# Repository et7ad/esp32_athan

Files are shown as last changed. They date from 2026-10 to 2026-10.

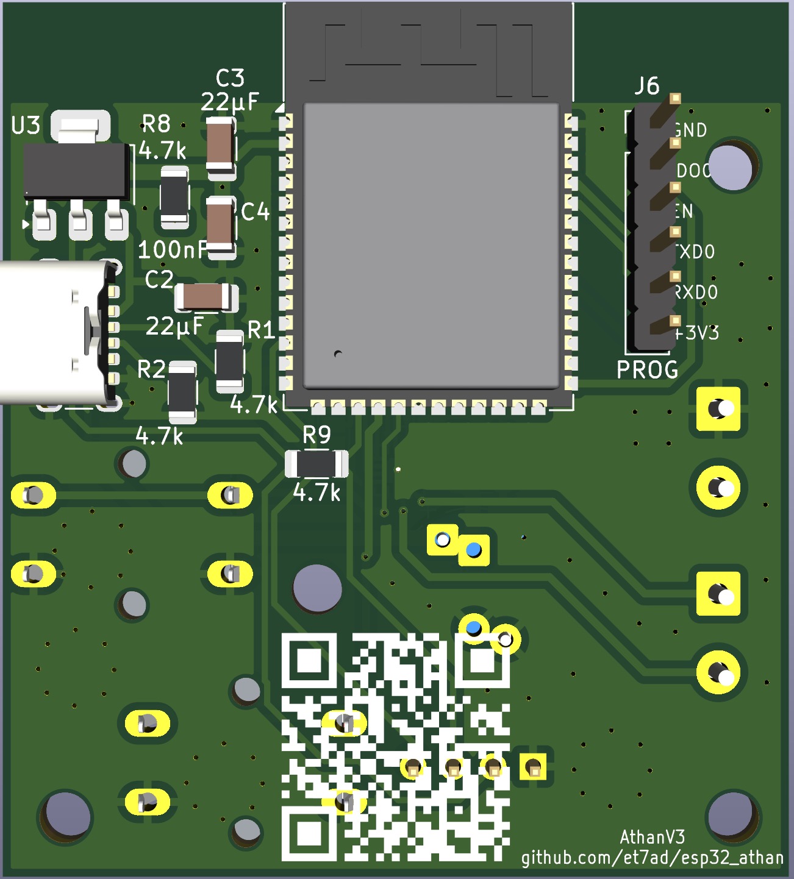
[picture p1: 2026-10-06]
hardware/pcb/generated_imgs_and_3d/Front_with_3D.jpg

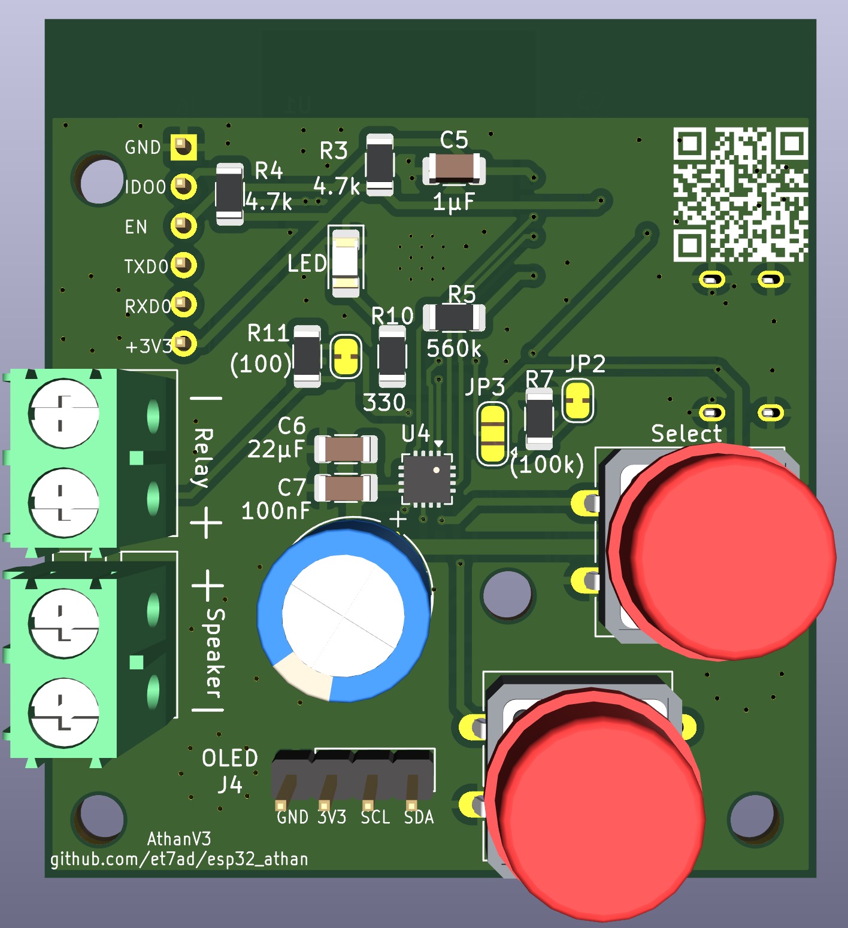
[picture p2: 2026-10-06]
hardware/pcb/generated_imgs_and_3d/Back_with_3D.jpg

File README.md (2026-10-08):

# Athan clock, version 3 (ESP32-S3)

A small Wi-Fi clock that calls the athan at the prayer times of your mosque, shows the time and the next prayer on
a little OLED screen, plays Quran radio, and can switch an external relay (for example a mosque speaker) before
Fajr. Version 3 runs on an ESP32-S3 with a MAX98357A amplifier: the audio is stored in the ESP's own flash and
played by the ESP itself.

> **Have an older clock (ESP8266 + DFPlayer, "V2")?** Its firmware and prayer data live in
> [et7ad/esp_athan](https://github.com/et7ad/esp_athan). That repository is kept only to support existing V2
> devices. New builds should use this repository.

**Status (October 2026):** firmware 3.0.0 is written and type-checked but **not yet tested on hardware**. The
prototype checklist is in [version3_planning.md](version3_planning.md) section 13. The board (KiCad) and the
enclosure are still to be drawn from [HARDWARE.md](HARDWARE.md).

## What it does

- Calls the athan at Dhuhr, Asr, Maghrib and Isha, and a separate Fajr athan at Fajr, each at its own volume.
  Each prayer can be switched off on its own.
- Keeps a whole year of your mosque's prayer times in flash. Once the clock is set, the athan keeps working
  without internet.
- Plays internet radio from ten slots. By default they follow this project's station list; any slot can play
  your own link instead.
- **Pre-Fajr Tawashih:** 25 minutes before Fajr it switches the relay on, plays a tawashih, and switches the
  relay off after 15 minutes. Off by default.
- Plays an hourly tick inside a time window you choose, or not at all.
- Every sound (athan, Fajr athan, tawashih, tick) can be swapped for another from the project's list, or for a
  file you upload. Each file is checked before it replaces the old one.
- It is set up from a phone over Bluetooth, or through its own Wi-Fi hotspot.
- It has a web page, works with Home Assistant, and updates its own firmware from GitHub Releases.
- It keeps working without the screen: if the OLED fails, the athan still plays.

## Contents

1. [Using the clock](#1-using-the-clock)
2. [Building one](#2-building-one)
3. [Maintaining the data (project owner)](#3-maintaining-the-data-project-owner)
4. [Repository layout](#4-repository-layout)

---

## 1. Using the clock

### 1.1 First setup: connect it to Wi-Fi

Plug the clock into a USB-C charger (5 V, 2 A). A new clock, or one that cannot reach its saved network, opens
**two setup methods at once**. Use whichever suits your phone; the first one to finish wins.

**Method 1: Bluetooth (Android, computers, Home Assistant app)**

1. On an Android phone or a computer, open **Chrome** or **Edge** and go to <https://www.improv-wifi.com>. Then
   press **Connect** and pick the device named **athan**. Instead, if you use Home Assistant, the Companion app
   finds the clock by itself and offers to set it up.
2. When the screen shows **BT: press Select**, press the **Select** button on the clock. Like commercial smart-home
   devices, this proves you are standing next to it. The permission lasts one minute.
3. Choose your network and type its password. The clock joins and Bluetooth turns off.

**Method 2: hotspot (every phone, including iPhone)**

iPhones cannot use Method 1 without the Home Assistant app, because Safari has no Web Bluetooth.

1. On your phone's Wi-Fi list, join **AthanFallbackHotspot**. The password is **athan404**.
2. The setup page opens by itself. If it doesn't, open <http://192.168.4.1>.
3. Pick your network, type the password and save. The clock restarts and joins.

On a new clock both start right away. When a saved network has gone away, Bluetooth starts after 15 seconds and
the hotspot after about 3 minutes, so a short router restart never opens it.

**Forget the saved Wi-Fi:** unplug the clock, hold **Select** (press the joystick straight in), and plug it back
in. The LED blinks three times, the clock restarts, and it enters setup mode (Bluetooth after 15 seconds, the
hotspot after about 3 minutes).

**Your mosque:** a new clock starts with the first mosque in the list (Davis). Choose yours from the menu
(**Location**) or on the web page. The clock downloads that mosque's year of prayer times. It also downloads
the default sounds the first time it is online, which takes a few minutes.

### 1.2 The screen

Normal screen:

```text
14:05  05Oct        time and date
Asr 16:42 ▫         next prayer and its time
Rem 02:37      ▸ 🔒  time remaining, and status marks
```

| Mark | Meaning |
|---|---|
| Small hollow square after the next prayer's time | **Estimated time.** This year's timetable is not published yet, so the clock uses the same date of last year (converted for daylight saving; at most about a minute off). It disappears when the real timetable arrives. Mosques often publish late, sometimes days into January, so this is normal |
| Last two letters of the prayer's name struck through | The athan for that prayer is switched off |
| Small filled triangle with a number, bottom right | The radio is playing; the number is the radio slot (1–10). **Up** stops it |
| Padlock, bottom right | The buttons are locked (1.3) |
| Circled, crossed-out **W** | No Wi-Fi. The athan keeps working from the stored times |

Other screens:
- **Athan Time: Asr prayer** while the athan plays.
- **A box over the clock for 2 seconds** after Left/Right (the volume and a bar) or Down (Relay ON/OFF).
- **Struck-through rows** (lines through all three rows, with `--:--` where nothing is known) until the clock is set
  after a power-up; lines through rows 2 and 3 only until the day's prayer times are loaded. As on V2.
- **Wi-Fi setup:** while Bluetooth setup or the hotspot is open, it shows `BT: press Select` / `BT: allowed` /
  `BT: joining..` and `Hotspot: on` / `Hotspot: soon`.

### 1.3 Buttons

The clock has one **5-way joystick**: **Up**, **Down**, **Left**, **Right**, and **Select** (press it straight in).

On the clock screen:

| Key | What it does |
|---|---|
| **Left / Right** | Volume down / up by 10 %, shown for 2 seconds. It changes the volume of whatever plays (the Fajr volume during the Fajr athan or the tawashih) and never stops it. With nothing playing, a short tone plays at the new volume. The keys stop at 10 %; 0 % (silent) is only in the menu or on the web page |
| **Up** | Radio on or off. It plays the station chosen last (the number beside the play mark) |
| **Down** | Relay output on or off |
| **Select** | Opens the menu |

While the athan, the tawashih, the tick or a preview plays, **Up**, **Down** and **Select** stop it instead. The
radio is the exception: it keeps playing, so Up stops it, Select opens the menu and Down switches the relay as usual.
Stopping the athan also cancels the radio's automatic resume.

**The menu** is two wheels. **Up/Down** move between the menu's rows; the row's name is at the top, and each row is
live as soon as you reach it: no "open" step. **Left/Right** move through that row's choices. Around the item in the
middle you see small previews of what is next: the choices to the left and right, the rows above and below with
their current setting. A **check mark** marks what is in use, a **play mark** the radio station playing. Dots under
the item show where you are in the row.

**Select** takes the choice shown. Where nothing needs taking (the choice already in use, a volume, the tick
hours, Info) it closes the menu. Up from the first row or Down from the last also returns to the clock (the small
preview there says **Home**), and so does 60 seconds without a press.

| Row | Left/Right | Select |
|---|---|---|
| **Radio** | The ten radio slots (opens on the one chosen last) | Plays the slot shown, or stops it if it is playing, and returns to the clock |
| **Athan** | The suggested athans, and **Custom** first if you uploaded one. Rest on one for half a second and its preview plays; the one in use plays from the device. The row opens on the athan in use and previews it (not while the radio plays: then only Left/Right preview, and the radio comes back when the menu closes) | Downloads the one shown and makes it the athan. Progress shows under it; the old sound stays until the new one has passed every check, then the check mark moves. Custom disappears once a download replaces it |
| **Fajr Athan** | The same, for the Fajr athan. Previews play at the Fajr volume | The same |
| **Tawashih** | The same, for the Pre-Fajr Tawashih | The same |
| **Pre-Fajr** | Off, On | Takes it |
| **Hourly Tick** | The ticks, with **Off** first | Takes it; any tick switches the hourly tick on |
| **Tick From**, **Tick Until** | The hour, at once. The line under it shows the window; From = Until means all day | Closes |
| **Athan On/Off** | Fajr, Dhuhr, Asr, Maghrib, Isha, each with On/Off | Switches the prayer shown |
| **Volume**, **Fajr Volume** | 0–100 %, at once, with a tone at the new level | Closes |
| **Location** | The mosques | Takes it; the clock downloads its prayer times |
| **Clock** | 24-hour, 12-hour | Takes it |
| **Update** | — | Checks GitHub for new firmware; when there is one, the item becomes **Install 3.x.y** and Select installs it. `Check failed` means GitHub has no release yet or the clock is offline |
| **Lock Buttons** | — | Locks the buttons and returns to the clock |
| **Info** | IP address, `athan.local`, firmware version | Closes |

**Button lock**, for clocks within children's reach: while locked, any key only stops what is playing. To unlock,
use the **Buttons Locked** switch on the web page, or unplug the clock and plug it back in while holding **any of
the four directions**: the LED blinks three times quickly. (Holding Select instead forgets the Wi-Fi, 1.1.)

### 1.4 The web page

Open **<http://athan.local>**. If that doesn't work, use the IP address from the **Info** screen. The page is
grouped:

- **Now:** Stop Audio, Athan Playing, Next Prayer, Today's Times, Buttons Locked, 12-hour Clock.
- **Athan:** Volume, Fajr Volume, Pre-Fajr Tawashih, Hourly Tick, Tick Window Start / End.
- **Athan On/Off per Prayer:** one switch per prayer.
- **Sounds:** the selected sounds, the last download's status, and the link to the sounds page (1.5).
- **Radio:** Radio Station, Play Radio, Stop Radio, Radio Status.
- **Radio Stations:** the ten slots (1.6).
- **Location and Prayer Times:** Location, Refresh Prayer Times, Prayer Data (which years are stored).
- **System:** Firmware Version (this build, and whether GitHub has a newer one), Firmware (install updates), Check
  For Update, Restart, External Relay, IP address, **Wi-Fi Signal**, **Wi-Fi Drops** (when and why the router dropped
  the clock, the last three), memory.

The same entities show up in Home Assistant when you add the device there (ESPHome integration).

### 1.5 Changing the sounds: <http://athan.local/audio>

Open it from the **Change Sounds At** link on the device page, or type the address. A status bar stays at the top
of the page, with a **Stop** button for previews. Every button reports there, so the page never reloads or jumps
back to the top. After a download or upload, the bar offers **Reload page** to show the new sound. For each of
the four sounds (athan, Fajr athan, tawashih, hourly tick), the page shows:

- **Selected:** the name and length of the sound stored on the clock, the one it plays.
- **The suggested list** from this project, with **Preview** and **Download** for each entry. The selected entry is
  marked *selected*. Preview stores nothing: the selected entry plays from the clock, any other streams from the
  internet. Download fetches the entry, checks it, and only then replaces the selected sound. Downloading the
  selected entry does nothing. To fetch it again, download another entry and then this one.
- **Upload your own:** pick an MP3 file on your phone or computer and press Upload. The uploaded sound then shows
  at the top of the list as **Custom**, with **Preview**, and in the clock's menu as **Custom** too. It stays
  until you download a list entry for that sound, which replaces it.

Limits, checked before anything is replaced:

| Sound | Largest file | Longest |
|---|---|---|
| Athan, Fajr athan, tawashih | 3 MB | 5 minutes |
| Hourly tick | 0.4 MB | 1 minute |

The file must be an MP3. A 5-minute recording fits in 3 MB at 64 kbps mono.

**The clock plays only the left channel.** A mono file always plays in full. A stereo file plays only its left
channel, so the whole sound must be in that channel. A recording with something only on the right (a voice or an
echo) loses it. Converting the file to mono, as below, makes any recording safe. The amplifier is wired for left
only because its mono-mix mode caused audible artifacts during testing.

#### Quick way: an online converter (nothing to install)

1. Open [online-convert.com's MP3 converter](https://audio.online-convert.com/convert-to-mp3) (free, in the
   browser) and choose your file. It also takes WAV, M4A or a video.
2. In the optional settings, set **Change audio channels** to **Mono** and **Change audio sample rate** to
   **44100 Hz**. Set the bitrate to **64 kbps** (48 kbps for an hourly tick).
3. Convert, download the result, and upload it on the clock's `/audio` page. The clock checks every file first
   (MP3, size, length) and says what is wrong if it doesn't fit.

Your file goes to that service's servers. To keep it on your computer, or to cut a long recording to the limit,
use ffmpeg instead.

#### Preparing your own file with ffmpeg

1. Install [ffmpeg](https://ffmpeg.org) once: `brew install ffmpeg` (macOS), `winget install ffmpeg` (Windows) or
   `sudo apt install ffmpeg` (Debian, Ubuntu).
2. See what the file is:

   ```bash
   ffprobe -v error -show_entries stream=channels,sample_rate:format=duration,size -of default=nw=1 in.mp3
   ```

   `channels=1` is mono, `channels=2` is stereo. `duration` is in seconds and `size` in bytes; compare them with
   the limits above.
3. Convert it to mono. This mixes both channels into one, so nothing from either side is lost:

   ```bash
   ffmpeg -i in.mp3 -map 0:a -map_metadata -1 -ac 1 -ar 44100 -b:a 64k out.mp3
   ```

   | Part | What it does |
   |---|---|
   | `-map 0:a -map_metadata -1` | Keeps only the audio, without cover art or tags (the clock does not need them) |
   | `-ac 1` | One channel: mono |
   | `-ar 44100` | 44.1 kHz, the clock's own rate, so it plays without resampling |
   | `-b:a 64k` | 64 kbps: 5 minutes ≈ 2.4 MB. For an hourly tick use `-b:a 48k` |

   The input can be any format ffmpeg reads (WAV, M4A, a video, …). The output is MP3 because the name ends in
   `.mp3`.
4. If the mono version sounds hollow or thin (the two channels cancel each other, which is rare), or one channel
   is only noise, keep a single channel instead of mixing. Replace `-ac 1` with `-af "pan=mono|c0=c0"` for the
   left channel, or `-af "pan=mono|c0=c1"` for the right one.
5. If it is longer than the limit, add `-t 300` (5 minutes) or, for a tick, `-t 60` before `out.mp3` to cut it
   there.
6. Run the `ffprobe` command from step 2 on `out.mp3`: it should say `channels=1` and fit the limits. Then upload
   it.

A failed download, a file that is too big or
too long, or a file that is not MP3 never touches the selected sound. The page says why it refused. A download
is refused while that sound is playing.

### 1.6 Radio

There are ten slots. Each one has two settings on the web page:

- **Radio N follows project list** (on by default): the slot plays station N of this project's list,
  [docs/radio/stations.json](docs/radio/stations.json). The clock keeps the list in memory, loaded at start-up
  and refreshed every 6 hours, so a station starts at once and switching between them is quick. If a station
  moves, the project updates the list and every clock follows within 6 hours (sooner if that station stops
  working on a clock).
- **Radio N own link:** switch "follows project list" off and paste a stream link here (see "Adding your own
  station" below). The screen then shows "own link" for that slot instead of a station name.

Play it from the menu (**Radio**), or with **Radio Station** + **Play Radio** on the web page. The **Radio
Station** list shows each slot's name from the project list ("Radio 1 Cairo Quran"), "(own link)" for a slot
with its own link, and just "Radio N" until the list has loaded. Reload the page to see names that loaded after
it opened.

- **At prayer time** the athan pauses the radio, and the same station comes back when the athan ends. The
  Pre-Fajr Tawashih does the same. If you stop the athan yourself, the radio stays off.
- **The hourly tick** plays over the radio while the radio is turned down for a moment.
- **If Wi-Fi drops** (the router restarts, or drops the clock for a moment), the radio pauses and starts again by
  itself as soon as Wi-Fi is back; after 10 minutes without Wi-Fi it switches off. Pressing Up while Wi-Fi is down
  starts the radio once it is back.
- **If the station itself fails** (down, or no internet behind the router), the clock tries three more times, 3, 6
  and 9 seconds apart, then stops and shows the reason under Radio Status.
- **Right speed, always:** stations sometimes change format between recordings (mono or stereo, 44.1 or 22 kHz),
  and the clock joins a live stream in the middle of its data. The player follows every format change on its own,
  so Quran never plays sped up or slowed down. As a second check, the clock reads the station's format itself 10
  seconds after a start and every 10 minutes, and restarts the stream if what plays does not match. The stored
  sounds are checked the same way.

#### If the router keeps dropping the clock

The web page's **Wi-Fi Drops** (System) lists when and why. "Not authenticated", "not associated" and
"deauthenticated by the router" all mean the router itself gave up on the clock. The clock already uses the
settings that help most (802.11b/g only, Wi-Fi power saving off, lower transmit power right next to the router).
On the router, in this order:

1. Don't put the clock right beside the router: a **Wi-Fi Signal** stronger than about −30 dBm is too close.
   One or two metres away is ideal.
2. Give the 2.4 GHz band its own network name (turn off "Smart Connect" / band steering), on a fixed channel
   (1, 6 or 11) at 20 MHz width.
3. Security: WPA2-PSK (AES) only, not a WPA2/WPA3 mix; management frame protection (PMF/802.11w) optional or off.
4. Turn off, at least for 2.4 GHz: beamforming, airtime fairness, OFDMA / MU-MIMO, TWT (Wi-Fi 6 features the
   ESP32's 802.11b/g/n radio does not use). On a TP-Link Deco: also Fast Roaming, and Mesh Technology for the clock.
5. If drops come at a fixed interval, raise the router's group key update interval (for example to 3600 s).
6. Update the router's firmware.

#### Adding your own station

A link works when all of these are true:

- **It is the stream itself**, not a web page with a player. Pages on TuneIn, YouTube or a station's own site do
  not work. If the link opens a bare audio player in the browser and starts playing, it is a stream.
- **The format is MP3**, the safest choice, or Opus, FLAC or WAV. The clock reads the format from the server's
  `Content-Type` (`audio/mpeg`, `audio/ogg; codecs=opus`, `audio/flac`, `audio/wav`). If the server sends no type
  it knows, it reads the link's ending (`.mp3`, `.opus`, `.flac`, `.wav`). **Not supported:** AAC or AAC+
  (`audio/aac`, `audio/aacp`, common on Shoutcast stations), Ogg Vorbis, and HLS (`.m3u8`).
- **It is not a playlist file.** A `.m3u` or `.pls` link is a small text file: open it in a text editor and paste
  the `http…` line inside it.
- **`http://` or `https://`.** HTTPS needs a certificate from a common authority; for a site with a self-signed
  certificate, use its `http://` link. An `https://` link that forwards to an `http://` server is refused, so
  paste the `http://` form instead. The project's Cairo station is an example (3.3).
- **It does not expire.** Some services forward to a link with a one-time token (`…?rj-tok=…`) that stops
  working within seconds. Paste the link from before the forward, never the one the browser ends up on.
- **At most 255 characters.**

A stereo station plays only its left channel (1.5). That loses nothing on nearly every station, because both
channels carry the same sound. Any sample rate works; 44.1 kHz plays without resampling. 64 to 128 kbps MP3 is
plenty for one speaker.

**Where to find links:**

- **Quran stations:** [mp3quran.net/eng/radios](https://www.mp3quran.net/eng/radios) lists over 170 stations by
  reciter, all MP3 over HTTPS. The project's own list uses these. The same list as data, with each station's
  `url`: <https://www.mp3quran.net/api/v3/radios?language=eng>.
- **Any station:** [radio-browser.info](https://www.radio-browser.info) is an open directory of tens of thousands
  of stations. Search for one, check that its codec says **MP3**, and copy its stream link.
- **A station's own website:** look for "direct link", "listen in your player" or a `.m3u` / `.pls` download.
  Another way: in Chrome, start the station's web player, open **Developer Tools → Network → Media**, and copy the
  address of the request that keeps loading. Skip it if that address ends in `.m3u8` (HLS).

**Test a link before pasting it** (macOS and Linux have `curl`; on Windows use PowerShell's `curl.exe`):

```bash
curl -sI -X GET --max-time 5 <link>
```

You want `HTTP/… 200` and a `content-type` from the list above. A `302` with `location: https://…` is fine: the
clock follows up to five forwards. A `location: http://…` answer to an `https://` link means: use `http://`. Then
paste it into **Radio N own link**, switch **Radio N follows project list** off, and play the slot.

### 1.7 Prayer times

- The clock stores your mosque's whole year (one download). After that it only needs the internet to set the clock
  after a power cut.
- **Next year** is looked for every day from 1 December. "Not published yet" is normal and is not an error.
- **From 1 January,** if the new timetable is still missing, the clock uses last year's times for the same date
  and shows the hollow-square mark (1.2). It checks every 6 hours and switches the moment the timetable appears.
- **Refresh Prayer Times** (web page) downloads the current year again. Use it if your mosque corrected its
  timetable.
- After a power cut **with no internet**, the clock has no time until the internet comes back, then it carries
  on by itself.

Mosques available now:

| Key (Location) | Mosque | Years |
|---|---|---|
| `davis` | Islamic Center of Davis | 2025–2027 |
| `sclaramca` | MCA Santa Clara | 2025–2026 |
| `sclaraalnoor` | Masjid Al-Noor, Santa Clara | 2025–2026 |
| `woodland` | Woodland Mosque | 2026–2027 |
| `masjid15` | Visalia, California (times from IslamicFinder) | 2026–2027 |

To add your mosque, open an issue or send its yearly timetable. Section 3.1 shows how it is added.

### 1.8 Updates

The clock checks this repository's latest GitHub Release every 6 hours. To install an update, use **Firmware** on
the web page, the **Update** menu item, or Home Assistant. Your settings, sounds and prayer times stay.

**Firmware Version** on the web page always shows the installed version (for example `3.0.0 (latest)` or
`3.0.0 (3.0.1 available)`). ESPHome's own **Firmware** entry shows `UNKNOWN`, with no version, until a check has
succeeded once. That needs a published release (3.4) and internet.

---

## 2. Building one

### 2.1 Hardware

| Part | |
|---|---|
| ESP32-S3-WROOM-1-**N16R8** module (16 MB flash, 8 MB PSRAM), LCSC C2913202 | the board's processor |
| MAX98357A amplifier (MAX98357AETE+T, LCSC C910544) | I2S DAC + 3 W amplifier |
| 4 Ω 3 W speaker, SSD1306 128×64 I2C OLED, a 5-way joystick switch (10 × 10 mm), an LED | |
| USB-C 6-pin (power only), 3.3 V LDO, passives | |
| 1×6 programming header (J6) + a 3.3 V USB-serial adapter (CP2102/CH340) | first flash only |

The full parts list, the pin map, and instructions for the PCB and the enclosure are in
[HARDWARE.md](HARDWARE.md). The amplifier circuit is in [max98357a_amplifier.md](max98357a_amplifier.md).

**Prototype on a breadboard** first: an **ESP32-S3-DevKitC-1 N16R8** (same module), an Adafruit MAX98357A breakout
(3006) or a clone, and the OLED, the 5-way switch and speaker. The wiring is in HARDWARE.md section 2. The firmware and
flash layout are the same as on the final board. Wire the breakout's SD pin to GPIO15 through 4.7 kΩ (left
channel). Left unconnected, SD puts the breakout in its mono-mix mode, which gives audible artifacts.

### 2.2 Firmware

You need [ESPHome](https://esphome.io) **2026.9 or newer**. The firmware was written against 2026.9.1. The
easiest way is **`./build_firmware.sh`** in the repository root (macOS or Linux, Python 3.12–3.14). It installs
that exact ESPHome into its own environment on the first run, with no Docker or dashboard. It keeps ESPHome, the
toolchain (about 1 GB) and the build in `~/.cache/esp32_athan`, so nothing is written into the repository except
the finished binaries in `firmware/binaries/`.

| Command | Does |
|---|---|
| `./build_firmware.sh` | Build. Writes `athan-v3-<version>.factory.bin`, `athan-v3.ota.bin` and `manifest.json` to `firmware/binaries/` |
| `./build_firmware.sh flash [PORT]` | Build and flash over a serial port: the V3 board's J6 adapter (`/dev/cu.usbserial…`) or a DevKitC's USB (`/dev/cu.usbmodem…`). Without PORT it lists the ports |
| `./build_firmware.sh ota [HOST]` | Build and update over Wi-Fi (default `athan.local`) |
| `./build_firmware.sh logs [PORT\|HOST]` | Show the device's log |
| `./build_firmware.sh check` | Validate the yaml only (seconds, no compile) |
| `./build_firmware.sh clean [all]` | Delete the build (`all`: also ESPHome and the toolchain) |

`flash` and `ota` above always build first. When nothing changed that build is quick, but it still takes tens of
seconds. To send binaries that already exist (your last build, or files downloaded from a GitHub Release) without
building, use **`./flash_firmware.sh`**:

| Command | Does |
|---|---|
| `./flash_firmware.sh ota [HOST]` | Sends `firmware/binaries/athan-v3.ota.bin` over Wi-Fi. Keeps settings, Wi-Fi, sounds and prayer times |
| `./flash_firmware.sh usb [PORT]` | Same file over a serial port (J6 adapter or DevKitC USB), firmware only. Keeps everything. For a board that already runs V3 |
| `./flash_firmware.sh usb-full [PORT]` | The whole `athan-v3-<version>.factory.bin` from 0x0: a blank board, or after `partitions.csv` changed. Resets settings and Wi-Fi |

Add `-f FILE` to flash another file. Every file is checked to be an ESP32-S3 image of the right kind first.
Wi-Fi updates (from both scripts) go only to a clock that serves the V3 `/audio` page. A V2 clock also answers to
`athan.local` and an ESP32 image would brick it.

1. **Put the two menu tones** in `firmware/sounds/`: `click.mp3` (the menu click) and `volume.mp3` (the volume
   tone). Any short MP3s work. The V2 SD card's `C3` and `C2` are the original ones. They are built into the
   firmware.
2. **Optional, recommended for your own builds:** generate your own API encryption key (`openssl rand -base64 32`)
   and put it in both `api:` and `ota:` in `firmware/athan.yaml`. You don't need Wi-Fi credentials or
   `secrets.yaml`: Wi-Fi is set up from the phone (1.1).
3. **First flash through J6.** The V3 board's 6-pin USB-C carries power only, so the first flash uses a 3.3 V
   USB-serial adapter on the J6 header (HARDWARE.md 3.2). It also writes the bootloader and the partition table:
   1. Wire the adapter: GND → J6 pin 1, adapter RX → pin 4, adapter TX → pin 5.
   2. Put the jumper cap on J6 pins 1–2 (IO0 to GND), then plug the board's USB-C into a charger.
   3. Flash, choosing the adapter's port:

      ```bash
      ./build_firmware.sh flash        # or, with your own ESPHome: esphome run firmware/athan.yaml
      ```

   4. Remove the jumper, then unplug and replug the USB-C.

   On a DevKitC prototype, just plug in its USB port; it enters download mode by itself. Serial logs come out on
   UART0 (J6 pins 4/5, or the DevKitC's UART port): `./build_firmware.sh logs /dev/cu.usbserial-…`. How much it
   logs is `log_level` at the top of `firmware/athan.yaml`: `DEBUG` while testing, `WARN` (or `NONE`) for a
   finished build.
4. Later flashes can go over Wi-Fi (`./build_firmware.sh ota`), or the clock can update itself from GitHub
   Releases (3.4).

**ESPHome dashboard (Docker) instead of the command line:** copy the *contents* of `firmware/` into the dashboard's
config folder: `athan.yaml`, `partitions.csv`, `web_audio_link.js`, `components/` and `sounds/`. The yaml finds
them by relative path.
Make sure the dashboard image is 2026.9 or newer (`docker pull esphome/esphome:latest`).

**A V2 clock on the same network** is also called `athan`. Give one of them another `device_name` (substitution at
the top of the yaml, for example `athan3`), or `athan.local`, Home Assistant and the dashboard will mix them up.
In a shared dashboard config folder, also save the V3 yaml under another file name.

The first boot with internet downloads the default sounds, which are entry 1 of each list in
[docs/audio/catalog.json](docs/audio/catalog.json). Until then, an athan time is marked with three tones.

Internals are in [DEVELOPER.md](DEVELOPER.md), and the design reasoning is in
[version3_planning.md](version3_planning.md).

---

## 3. Maintaining the data (project owner)

Everything the clocks download lives under `docs/` on branch `main` and is read over HTTPS from
`https://raw.githubusercontent.com/et7ad/esp32_athan/main/docs/...`. A change there reaches every clock without a
firmware update.

### 3.1 Prayer times

One file per mosque per year: `docs/athantimes/<key>/<year>.json`. The format is in
[prayertimes_specs.md](prayertimes_specs.md): one list of 12 `HH:MM` times per day, true 24-hour, at most 100 KB.
All scripts are in `scripts/` and write exactly that one file. They check the times, warn about suspicious days
(adhan out of order, iqama before adhan, a change of more than 3 minutes from the same date last year), and
refuse a broken year.

| Your source | Script |
|---|---|
| A table (spreadsheet exported as a JSON list of rows) | `python3 scripts/source_to_yearly.py --key davis davis_2027.json` |
| IslamicFinder's yearly page (saved HTML) | `python3 scripts/parse_Islamicfinder/parse_islamicfinder_yearly.py --key masjid15 Visalia2027.html` |
| MCA Santa Clara PDF | `python3 scripts/santaclara_prayer_times_parser.py --key sclaramca 2027_MCA_Prayer_Time.pdf` |
| A year that only exists as V2 daily files | `python3 scripts/make_yearly_json.py --key davis --year 2027` (reads `../esp_athan`) |

Add `--dry-run` to check without writing. `python3 scripts/plot_prayer_times.py docs/athantimes` draws every
year as an HTML chart next to its file (needs `pip install plotly`), handy for spotting a typo by eye.

**Publish each new year as soon as the mosque publishes its timetable,** whether that is in November or some days
into January. V3 clocks pick it up within a day in December, or within 6 hours from 1 January. Until then they use
last year's times.

V2 clocks read **daily** files from the V2 repository. Produce those with the V2 repository's own scripts
(`break_json.py` and friends) and commit them there. The scripts here write only the V3 yearly files.

**Adding a mosque:**

1. Add an entry to [docs/athantimes/mosques.json](docs/athantimes/mosques.json): name, POSIX time zone (for
   example `PST8PDT,M3.2.0,M11.1.0`, not `America/Los_Angeles`), and how many minutes after sunrise Doha is.
2. Generate its yearly file(s) with one of the scripts above.
3. Add the key to the `options:` of the **Location** select in `firmware/athan.yaml`, in any position (clocks
   store the key, not the position), and release a firmware update (3.4).
4. Add it to the table in 1.7.

### 3.2 Sounds

`python3 scripts/prepare_audio.py` builds the whole library from the V2 SD-card recordings
(`../esp_athan/SDCard_files`: A → athan, F → fajr, D → tawashih, B → tick). Every file is rebuilt into one plain
format: MP3, mono, 48 kHz (the clock's own rate, so it never resamples), constant 64 kbps, no tags, no cover art,
no info frame. Each gets one plain gain so its decoded peak sits near −2 dBFS (no clipping, similar loudness),
and is checked to be exactly as long as its source; nothing is ever sped up or cut, and a recording over the
length limit is refused. Add `--check` to see what it would do without writing anything.

- The files go in `docs/audio/athan/`, `fajr/`, `tawashih/` and `tick/`, named `01.mp3` … `10.mp3`.
- Names and links go in [docs/audio/catalog.json](docs/audio/catalog.json). Each list holds up to 10 entries.
  Entry 1 is the default that new clocks download. A `url` can be relative to `docs/audio/` (`athan/01.mp3`) or a
  full https link.
- Names are plain ASCII and at most 12 characters, so they fit the screen.
- Every file must already pass the clock's checks (1.5). Re-encode big ones with the `ffmpeg` line in 1.5; use
  `48k` for ticks.
- Clocks re-read the catalog twice a day.

The catalog in this repository is a placeholder ("Athan 1" … "Athan 10") until the recordings are uploaded and
named.

### 3.3 Radio stations

[docs/radio/stations.json](docs/radio/stations.json) has exactly 10 entries; slot *k* of a subscribed clock plays
entry *k*. Change a link there and every subscribed clock uses it the next time that slot plays. An empty `url`
makes that slot empty for subscribers. Names follow the same 12-character rule. Every link must meet the rules
in 1.6 ("Adding your own station"); like the sounds (1.5), a stereo station plays only its left channel. Check
each link with
`curl -sI -X GET --max-time 5 <url>`. A `Location: http://…` answer to an `https://` link means the clock will
refuse it, because ESP-IDF blocks HTTPS-to-HTTP redirects. Use an HTTPS source that answers `200` directly, or
list the `http://` form. Egypt's Quran Radio is an example: its official radiojar link
(`stream.radiojar.com/8s5u5tpdtwzuv`) always redirects to HTTP, so slot 1 uses xecod.com's HTTPS relay. The
radiojar link, written with `http://`, is the fallback if the relay goes away.

### 3.4 Firmware releases

1. Raise `project_version` in `firmware/athan.yaml` (for example `3.0.1`) and run `./build_firmware.sh`. It
   writes `athan-v3.ota.bin` and a matching `manifest.json` into `firmware/binaries/`.
2. If you build another way (dashboard: ⋮ → Download → OTA format), make the two files from the **OTA** image (not
   the factory image) yourself:

   ```bash
   python3 scripts/make_release_manifest.py path/to/firmware.ota.bin --version 3.0.1 --summary "What changed"
   ```

3. Create a GitHub Release with tag `v3.0.1`, attach the two files it wrote (`athan-v3.ota.bin` and
   `manifest.json`), and mark it **latest**. Clocks see it within 6 hours.

A change to `firmware/partitions.csv` cannot be delivered this way. It needs a USB flash on every clock.

---

## 4. Repository layout

```text
firmware/
  athan.yaml               the whole device behaviour (ESPHome)
  partitions.csv           16 MB flash layout (app ×2, prayer years, sounds)
  web_audio_link.js        makes the device page's Change Sounds At value a link (web_server js_include)
  components/athan/        custom component: stored sounds, lists, radio, yearly prayer files, /audio page
  sounds/                  click.mp3 + volume.mp3 (built-in tones; you add them)
  tests/                   host unit tests and a type check (no ESP32 needed)
docs/                      everything the clocks download
  athantimes/              mosques.json + <key>/<year>.json
  audio/                   catalog.json + athan/ fajr/ tawashih/ tick/ (MP3s)
  radio/stations.json      the project's ten radio stations
scripts/                   prayer-time producers, plot, release manifest
hardware/pcb/              KiCad project (to be drawn from HARDWARE.md)
hardware/enclosure/        3D files (to be drawn from HARDWARE.md)
images/                    photos for this README
build_firmware.sh          build / flash / OTA / logs without Docker (2.2)
flash_firmware.sh          flash existing binaries over Wi-Fi or USB, no build (2.2)
README.md  HARDWARE.md  DEVELOPER.md  prayertimes_specs.md  version3_planning.md  max98357a_amplifier.md
CLAUDE.md                  notes for AI coding agents working in this repository
```

## License

See [LICENSE](LICENSE).

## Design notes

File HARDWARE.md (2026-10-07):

# Hardware: board, enclosure, wiring

Instructions for drawing the version 3 PCB in KiCad (`hardware/pcb/`) and the enclosure (`hardware/enclosure/`),
and for wiring a breadboard prototype first. The design decisions behind them are in `version3_planning.md`
sections 3 and 13. The amplifier circuit is in `max98357a_amplifier.md`. The firmware pin assignments are the
`pin_*` substitutions at the top of `firmware/athan.yaml`, so change both together.

Status: nothing is drawn yet. Build the prototype (section 2) and run its checklist before ordering boards.

## 1. Block diagram

```text
USB-C 6-pin (5 V only) ──┬── 5 V rail ──┬── MAX98357A (VDD) ── speaker terminal (OUTP/OUTN, 4 Ω 3 W)
   CC1/CC2 5.1 kΩ        │   bulk cap   │        ▲ I2S BCLK/LRCLK/DIN, SD_MODE (4.7 kΩ)
                         │              │        │
                         └── LDO 3.3 V ─┴── ESP32-S3-WROOM-1-N16R8 ── I2C ── OLED header (SSD1306)
                                                 ├── 5-way switch: Up/Down/Left/Right/Select (to GND)
                                                 ├── status LED
                                                 ├── relay output terminal (logic signal + GND)
                                                 └── UART0 + EN + IO0 ── J6 programming header
```

## 2. Prototype on a breadboard (do this first)

Parts: **ESP32-S3-DevKitC-1 N16R8**, an **Adafruit MAX98357A breakout (3006)** or a clone, the speaker, a
128×64 SSD1306 I2C OLED, the 5-way switch (3.5; five push buttons work too), an LED + 1 kΩ, and a 4.7 kΩ
resistor for the amp's SD pin.

| From (DevKitC pin) | To | Notes |
|---|---|---|
| 5V | breakout **Vin** | DevKitC's 5V pin carries USB VBUS when powered over USB |
| GND | breakout **GND**, OLED GND, switch **COM**, LED cathode | common ground |
| GPIO5 | breakout **BCLK** | |
| GPIO6 | breakout **LRC** | |
| GPIO7 | breakout **DIN** | |
| GPIO15 | breakout **SD**: see the note below | |
| breakout **GAIN** | open (9 dB) | other gains: `max98357a_amplifier.md` section 4 |
| breakout **+ / −** | speaker | |
| 3V3 | OLED VCC | |
| GPIO8 / GPIO9 | OLED SDA / SCL | most OLED modules already carry 4.7–10 kΩ pull-ups |
| GPIO14 | switch **Up** | internal pull-up; the switch's COM goes to GND |
| GPIO10 | switch **Down** | internal pull-up |
| GPIO21 | switch **Left** | internal pull-up |
| GPIO47 | switch **Right** | internal pull-up |
| GPIO11 | switch **Select** (centre push) | internal pull-up |
| GPIO12 | 1 kΩ → relay input (or an LED to see it) | |
| GPIO13 | 1 kΩ → LED → GND | status LED |

**SD on the breakout:** wire GPIO15 → 4.7 kΩ → SD, as on the PCB. The breakout's own 1 MΩ from SD to Vin can
stay: with GPIO15 low the 4.7 kΩ pulls SD to about 0.02 V (shutdown), with GPIO15 high to about 3.1 V (left
channel). Don't leave SD unconnected: the breakout then sits in its mono-mix mode, which gave audible artifacts in
testing, and it never shuts down.

Flash it over either DevKitC port and watch the log on its **UART** port: the firmware logs on UART0, which on the
final board is the J6 header. Then run `version3_planning.md` section 13. The firmware, partition table and pins
are the same as on the final board.

## 3. Schematic (KiCad)

Draw it as four blocks. Values come from the Espressif module datasheet (v1.8, "peripheral schematics"), the
Adafruit 3006 board and the plan. Net names in **bold** match the firmware.

### 3.1 Power and USB

- **USB-C receptacle, 6-pin, power only** (owner's choice 2026-10-05; KiCad symbol
  `Connector:USB_C_Receptacle_PowerOnly_6P`). Use V2's footprint
  `Connector_USB:USB_C_Receptacle_GCT_USB4125-xx-x_6P_TopMnt_Horizontal` if your connectors fit it, otherwise draw
  one from the seller's drawing:
  - VBUS (A9, B9) → **+5V** (through the polyfuse).
  - CC1 (A5) and CC2 (B5) → 5.1 kΩ each to GND. Without these, a C-to-C charger gives no power (the V2 board left
    them open).
  - GND (A12, B12) and the shield → GND.
  - No D+/D−: the ESP32-S3's own USB is not reachable, so the first flash and serial logs go through J6 (3.2).
    A 16-pin USB 2.0 receptacle (D+/D− to GPIO20/19 with a USBLC6-2SC6 ESD part) would bring back flashing and
    logs over the charging cable; it is a few cents more and needs the assembly service to solder.
- **Optional polyfuse** 1.5–2 A in VBUS (a footprint costs nothing).
- **5 V bulk** near the amplifier: about 470 µF in total. Either one SMD aluminium/polymer cap (6.3 V or more), or
  several 22–47 µF X5R ceramics (count with DC-bias derating). Keep everything on the front low; nothing tall.
- **3.3 V regulator,** at least 600 mA, for the module only. The amp runs from +5V.
  - AMS1117-3.3, SOT-223, LCSC C6186: 10 µF in. Its 22 µF output cap is the module's 22 µF below, so place the
    regulator next to the module.
  - Or a low-dropout part such as AP2112K-3.3 (600 mA) or AP7361C-33 (1 A). That leaves more margin when VBUS
    sags under amplifier peaks.
- **+3V3** at the module: 22 µF + 100 nF right at pin 2 (C3, C4 in the drawing).

### 3.2 ESP32-S3-WROOM-1-N16R8 (LCSC C2913202)

- GND pins and the exposed pad → GND (thermal vias under the pad).
- **Strapping pins, compared with the ESP8266:** the ESP-12E needed GPIO0 and GPIO2 pulled high, GPIO15 low, and
  RST/CH_PD high. The ESP32-S3 module has internal pulls on its boot pins that already select a normal boot, so the
  only part needed is on EN:

  | Pin | Needs | Why |
  |---|---|---|
  | EN | 10 kΩ to +3V3 + 1 µF to GND | must not float; the RC delays start-up until the 3.3 V rail is stable |
  | GPIO0 | nothing (optional 10 kΩ pull-up, DNP) | internal pull-up = normal boot; low during reset = download mode |
  | GPIO45 | nothing, **never pull high** | internal pull-down = 3.3 V flash supply; high = 1.8 V and the module won't boot |
  | GPIO46 | nothing | internal pull-down; must be low for download mode |
  | GPIO3 | nothing | JTAG source select, only with an eFuse burned |
  | RST, GPIO2, GPIO15 | nothing | not straps on the S3 (EN is the reset; GPIO15 drives the amp's SD here) |

  No DTR/RTS auto-reset transistors: one jumper cap on J6 selects download mode instead.
- **EN:** 10 kΩ to +3V3 + 1 µF to GND (power-on delay), and to J6.
- **J6 programming header,** 1×6 2.54 mm, populated (a jumper cap stays with the board). GND sits next to IO0, so
  a jumper on pins 1–2 at power-up selects download mode:

  | J6 pin | 1 | 2 | 3 | 4 | 5 | 6 |
  |---|---|---|---|---|---|---|
  | Net | GND | IO0 (GPIO0) | EN | TXD0 (GPIO43) | RXD0 (GPIO44) | +3V3 |
  | USB-serial adapter | GND | jumper to pin 1 | — | adapter RX | adapter TX | leave open |

  Use a 3.3 V adapter (CP2102, or a CH340 set to 3.3 V). Power the board from its USB-C while flashing; the
  adapter's 3.3 V pin cannot supply the module's Wi-Fi current peaks. An ESP-Prog works too and needs no jumper
  (it drives EN and IO0 itself, wired to J6 pins 3 and 2).
- **USB_D− (GPIO19), USB_D+ (GPIO20):** not connected (power-only USB-C).
- Leave unconnected: GPIO3, GPIO45, GPIO46 (straps), GPIO26–32 (flash), GPIO33–37 (octal PSRAM on R8 modules).

| Signal | GPIO | Goes to |
|---|---|---|
| **I2S_BCLK** | 5 | MAX98357A BCLK (pin 16) |
| **I2S_LRCLK** | 6 | MAX98357A LRCLK (pin 14) |
| **I2S_DOUT** | 7 | MAX98357A DIN (pin 1) |
| **AMP_SD** | 15 | 4.7 kΩ → MAX98357A SD_MODE (pin 4), left channel |
| **I2C_SDA** | 8 | OLED header SDA, 4.7 kΩ to +3V3 |
| **I2C_SCL** | 9 | OLED header SCL, 4.7 kΩ to +3V3 |
| **BTN_UP** | 14 | 5-way switch Up (3.5) |
| **BTN_DOWN** | 10 | 5-way switch Down |
| **BTN_LEFT** | 21 | 5-way switch Left |
| **BTN_RIGHT** | 47 | 5-way switch Right |
| **BTN_SELECT** | 11 | 5-way switch centre push |
| **RELAY_OUT** | 12 | 1 kΩ → relay terminal pin 1 (pin 2 = GND) |
| **LED** | 13 | 1 kΩ → LED → GND |
| **TXD0 / RXD0** | 43 / 44 | J6 pins 4 / 5 (UART0: flashing and logs) |

### 3.3 Amplifier

Copy `max98357a_amplifier.md` section 3 exactly:

- MAX98357AETE+T (LCSC C910544), TQFN-16 with exposed pad to GND.
- 10 µF + 100 nF at VDD.
- SD_MODE through 4.7 kΩ from GPIO15: high = left channel only, low = shutdown.
- 2×3 gain jumper header (no jumper = 9 dB). As `Conn_02x03_Odd_Even`: pins 3 and 4 = GAIN, 2 = +5V (2–4: 6 dB),
  6 = GND (4–6: 12 dB), 1 = 100 kΩ to +5V (1–3: 3 dB), 5 = 100 kΩ to GND (3–5: 15 dB).
- OUTP/OUTN straight to the speaker terminal, no output filter.

Add footprints for the optional EMI filter (section 8 there) only if you want the option later, populated with
0 Ω / DNP.

### 3.4 Back-side parts (through-hole, soldered from the front)

The same footprints as the V2 board (`../esp_athan/hardware/pcb/athan_kicad`):

| Part | Footprint (V2) |
|---|---|
| 5-way switch (SMD, hand-soldered: 3.5) | drawn from the seller's drawing |
| Speaker terminal, relay terminal | `TerminalBlock:TerminalBlock_MaiXu_MX126-5.0-02P_1x02_P5.00mm` |
| OLED header 1×4 (GND, VCC, SCL, SDA) | 2.54 mm pin header. **Print the order on the silkscreen**; modules differ (GND-VCC or VCC-GND first) |
| Status LED | 3 mm or 5 mm THT LED |
| Mounting holes | `MountingHole_3.2mm_M3` × 4 |

Removed compared with V2: DFPlayer, microSD, 3.5 mm jack, the on-board display footprint, speaker slide switch,
5 V screw-terminal input, the two push buttons (now one 5-way switch, 3.5). Kept: the 6-pin power-only USB-C (now
with CC resistors) and a programming header (J6, 1×6, new pin order).

### 3.5 The 5-way switch

The common 10 × 10 mm SMD 5-way switch with 6 pins (sold as Bestol, uxcell 10×10×9, TS-1505 type): four directions
and a centre push, each closing to one common pin. Only one key closes at a time.

- **Wiring:** COM → GND; each direction and the centre → its GPIO. No resistors: the firmware turns on the internal
  pull-ups (about 45 kΩ) and debounces (40 ms).
- **Pins:** GPIO10 and GPIO11 (the old Next and Select) plus **GPIO14, GPIO21, GPIO47**. All five sit on the module's
  bottom edge (module pins 18, 19, 22, 23, 24; GPIO12/13, relay and LED, are pins 20/21 between them), and none
  is a strapping, flash/PSRAM, USB or JTAG pin. GPIO47 runs at the flash voltage, 3.3 V on the N16R8 (it would be
  1.8 V only on the 1.8 V "V" modules). On a DevKitC-1, GPIO14 is on the left header next to GPIO13, and GPIO21
  and GPIO47 are on the right header.
- **Any assignment works.** The five lines are identical inputs, so route whatever is shortest and change the
  `pin_up` / `pin_down` / `pin_left` / `pin_right` / `pin_select` substitutions at the top of `firmware/athan.yaml`
  to match.
- **Pinout (community-reported for this switch type; sellers differ, so check yours):**

  | Pad | 1 | 2 | 3 | 4 | 5 | 6 |
  |---|---|---|---|---|---|---|
  | Function | **COM** (→ GND) | Left | Centre (Select) | Up | Right | Down |

  Check it with a meter in continuity mode before laying out: one probe on the pad you think is COM, then tilt
  the stem each way and press it in; each of the other five pads should beep for exactly one of them. If two pads
  beep for everything, the probe is not on COM.
- **Orientation:** "Up" is the direction the owner pushes, as they face the clock. The switch sits on the back of
  the board (3.4), so the side the owner sees is the mirror of the board's front view in KiCad: left and right
  swap. Name the nets by the owner's view, or swap `pin_left` / `pin_right` in the yaml after the first test.
- **Assembly:** the switch is SMD but sits on the back, where the board has only THT parts (one-sided assembly,
  section 5). Solder it by hand after assembly (its pads are large), or pay for assembly on both sides.
- **Footprint:** KiCad has none for this switch; draw it from the seller's drawing. The Ultra Librarian library in
  `hardware/pcb/libs/ul_SKQUCAA010/` is for the **Alps SKQUCAA010**, a different part: through-hole snap-in, its
  pins numbered 1 Up (A), 2 Left (B), 3 Down (C), 4 COM, 5 Right (D), 6 Centre (Alps datasheet), and listed by
  Alps as not recommended for new designs. Its footprint and numbering do not fit the SMD switch.

## 4. Bill of materials (per board)

| Qty | Part | LCSC | Side |
|---|---|---|---|
| 1 | ESP32-S3-WROOM-1-N16R8 (not the -1U) | C2913202 | front, SMD |
| 1 | MAX98357AETE+T | C910544 | front, SMD |
| 1 | USB-C receptacle, 6-pin power only (owner's part) | — | front |
| 1 | AMS1117-3.3 (or AP2112K-3.3 / AP7361C-33) | C6186 for AMS1117 | front |
| 2 | 5.1 kΩ (CC) | Basic part | front |
| 2 | 10 kΩ (EN; GPIO0 pull-up optional, DNP) | Basic part | front |
| 2 | 4.7 kΩ (I2C pull-ups) | Basic part | front |
| 2 | 100 kΩ (gain header: 3 dB and 15 dB positions) | Basic part | front |
| 2 | 1 kΩ (LED, relay) | Basic part | front |
| 1 | 4.7 kΩ (SD_MODE, left channel; anything 1–47 kΩ) | Basic part | front |
| 1 | 1 µF (EN) | Basic | front |
| 2 | 100 nF (3V3, amp VDD) | Basic | front |
| 1 | 22 µF (3V3 at the module, also the LDO output cap) | Basic | front |
| 2 | 10 µF (LDO in, amp VDD) | Basic | front |
| — | ≈ 470 µF bulk on 5 V (one SMD cap or several ceramics) | — | front |
| 1 | 2×3 pin header + 1 jumper (gain) | — | front or back |
| 1 | 5-way switch, 10 × 10 mm, 6-pin SMD (TS-1505 type, 3.5) | — | back, hand-soldered |
| 2 | MX126 2-pin 5.0 mm terminals | — | back, THT |
| 1 | 1×4 pin header (OLED) | — | back, THT |
| 1 | 1×6 pin header + 1 jumper cap (J6, programming) | — | back, THT |
| 1 | LED 3/5 mm | — | back, THT |
| 1 | SSD1306 128×64 I2C OLED module (0x3C; 0x3D works after changing `address:`) | — | wired |
| 1 | Speaker 4 Ω 3 W (same as V2) | — | wired |

Use JLCPCB's "Basic" parts wherever the value allows. The module and the amp are "Extended" (one-time setup fee
per part per order). The module is MSL 3, which the assembler handles.

### 4.1 Resistors and capacitors: through-hole or SMD

Every part has a through-hole and a hand-solderable SMD option (all checked on Digi-Key on 2026-10-05); pick per
part. The SMD options are 1206 size, and their footprints are KiCad's `HandSolder` variants with longer pads:
`Resistor_SMD:R_1206_3216Metric_Pad1.30x1.75mm_HandSolder` and `Capacitor_SMD:C_1206_3216Metric_Pad1.33x1.80mm_HandSolder`.
Through-hole resistors use `Resistor_THT:R_Axial_DIN0207_L6.3mm_D2.5mm_P7.62mm_Horizontal`, the TDK ceramics
`Capacitor_THT:C_Disc_D5.0mm_W2.5mm_P5.00mm` (5 mm lead spacing).

C4 (module 3V3) and C6, C7 (amp VDD) are better as SMD whichever way you solder: they only work well right at their
pins. If you fit them through-hole, put them within a few mm of the pins with short leads.

| Ref | Value | Through-hole | SMD |
|---|---|---|---|
| R1, R2 | 5.1 kΩ 1% | Yageo MFR-25FBF52-5K1 | Yageo RC1206FR-075K1L |
| R3 (R4 optional) | 10 kΩ 1% | Yageo MFR-25FBF52-10K | Yageo RC1206FR-0710KL |
| R5 | 4.7 kΩ 1% (any 1–47 kΩ) | Yageo MFR-25FBF52-4K7 | Yageo RC1206FR-074K7L |
| R6, R7 | 100 kΩ 1% | Yageo MFR-25FBF52-100K | Yageo RC1206FR-07100KL |
| R8, R9 | 4.7 kΩ 1% | Yageo MFR-25FBF52-4K7 | Yageo RC1206FR-074K7L |
| R10, R11 | 1 kΩ 1% | Yageo MFR-25FBF52-1K | Yageo RC1206FR-071KL |
| C1 | 470 µF 10 V low-ESR | Panasonic EEU-FR1A471, 8 × 11.5 mm, `CP_Radial_D8.0mm_P3.50mm` | Panasonic EEE-FK1A471P, 8 × 10.5 mm can, `CP_Elec_8x10.5` |
| C2, C6 | 10 µF 25 V X5R | TDK FG28X5R1E106MRT06 | Samsung CL31A106KAHNFNE |
| C3 | 22 µF 25 V electrolytic (suits the AMS1117) | Panasonic ECA-1EM220, `CP_Radial_D5.0mm_P2.00mm` | Panasonic EEE-FK1E220R, 5 mm can, `CP_Elec_5x5.8` |
| C4, C7 | 100 nF 50 V X7R | TDK FG28X7R1H104KNT06 | Samsung CL31B104KBCNNNC |
| C5 | 1 µF X7R | TDK FG28X7R1E105KRT06 (25 V) | KEMET C1206C105K5RACTU (50 V) |

## 5. PCB layout

1. **Antenna:** put the module's antenna end at a board edge, ideally overhanging it. Keep copper off both layers
   under and beside the antenna (follow the keep-out drawing in the module datasheet). No back-side parts, screws
   or speaker magnet near it.
2. **One-sided assembly:** every SMD part on the front. Back-side parts are THT, soldered from the front, so the
   PCB house assembles one side only.
3. **Amplifier:**
   - Short, direct I2S traces away from the antenna.
   - Solid ground under the amp, with thermal vias in its exposed pad.
   - Bulk and 10 µF + 100 nF right at VDD.
   - Wide OUTP/OUTN traces (≥ 0.5 mm) to the speaker terminal.
   - Details in `max98357a_amplifier.md` section 6.
4. **J6:** at a board edge the enclosure can reach (or that is easy to reach with the case open); the first
   flash needs it, later updates go over Wi-Fi.
5. **Ground:** a continuous ground pour on the back layer; stitch vias around the board and the amp.
6. **Power:** +5V from USB-C to the amp and the LDO with wide traces (≥ 1 mm). The amp's peaks are about 1 A.
7. **Silkscreen:** the switch's directions (arrows and "SEL"), the OLED pin order, gain jumper settings (3/6/9/12/15 dB, "open =
   9 dB"), terminal labels (SPK +/−, RELAY SIG/GND), board name and version "Athan V3", and the GitHub URL.
8. **Mechanical:** 4 × M3 holes matching the enclosure. Put the USB-C at an edge where the enclosure has its
   opening. Place the switch and LED where the enclosure's switch opening and light pipe sit.

Before ordering: run KiCad's DRC and ERC, compare the footprint pin-out of the module and the amp with their
datasheets, and check the 3D view for anything tall on the front.

## 6. Ordering (JLCPCB)

- 2-layer, 1.6 mm, HASL lead-free or ENIG (ENIG helps the TQFN), with assembly on the **top** side.
- Export from KiCad: Gerbers + drill, the BOM (Designator, Value, Footprint, LCSC) and the CPL (placement). Check
  the rotation of the module, the amp and the USB-C in JLCPCB's preview; they are often off by 90°/180°.
- Solder the THT parts yourself, or order THT assembly.

## 7. Enclosure (3D)

Start from the V2 enclosure, `../esp_athan/hardware/encolsure/Iteration13/` (`cover13.f3d` / `.step`, round and
rectangular speaker variants, two display variants), and adapt it:

| Item | Change from V2 |
|---|---|
| PCB mount | New outline and M3 hole positions from the V3 board |
| USB-C opening | Power only, as on V2; big enough for common cable boots (≈ 12 × 7 mm) |
| J6 | Reachable with the case open (first flash only), or a small slot if you want to reflash closed |
| Removed openings | No AUX jack, no SD card slot, no screw-terminal power input, no speaker slide switch |
| Switch | An opening or a cap over the 5-way switch's stem, room to tilt it in four directions and press it in |
| LED | Light pipe or hole over the LED |
| OLED | Window and clips for the 128×64 module; leave room for the 4-wire cable to the header |
| Speaker | Same speaker; a sealed back volume around it sounds fuller; grille holes in front of the cone |
| Antenna | No metal, screws or speaker magnet within ≈ 15 mm of the module's antenna end; plastic only there |
| Relay terminal | Cable exit or opening for the 2-wire relay lead |
| Ventilation | A few slots; the amp and ESP get warm at full volume |
| Labels | Embossed arrows around the switch, optional QR code to the README |

Put the exported STL/STEP/F3D files in `hardware/enclosure/`.

## 8. First power-on of a new board

1. Before fitting the module, or with it fitted but before USB: check +5V and +3V3 for shorts with a meter.
2. First flash through J6: wire a 3.3 V USB-serial adapter (GND → 1, adapter RX → 4, adapter TX → 5), put the
   jumper on J6 pins 1–2, and plug the board's USB-C into a charger. Run `./flash_firmware.sh usb-full` (or
   `./build_firmware.sh flash`) and pick the adapter's port. The first flash writes the partition table. Remove
   the jumper and unplug and replug the USB-C.
3. Logs on the same adapter: `./build_firmware.sh logs /dev/cu.usbserial-…` (UART0, 115200 baud). Look for
   `Athan:` in the config dump, `Slot athan: (empty)` on a new board, and the I2C scan finding 0x3C. Once Wi-Fi is
   set up, `./build_firmware.sh logs athan.local` works without the adapter, and updates go over Wi-Fi
   (`./flash_firmware.sh ota`).
4. Set up Wi-Fi (README 1.1). Within minutes the default sounds download. Play one from the menu at 10 %, then
   raise the volume and listen for clipping (that sets the gain jumper).
5. Run the full checklist in `version3_planning.md` section 13 on the first boards.

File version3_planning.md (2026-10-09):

# Athan clock version 3: planning

Date: 2026-10-04, updated 2026-10-05. Status: **firmware 3.0.0 implemented** in this repository
(`et7ad/esp32_athan`), type-checked and unit-tested on a computer, **not yet run on hardware**. The breadboard
prototype (section 13) comes next, then the PCB (`HARDWARE.md`). Section 0 lists where the implementation
differs from the plan below.

Version 3 is the third board (after `athanV1` and `athanV2`, whose KiCad files stay in the V2 repository
`et7ad/esp_athan`). It replaces the ESP8266 and the DFPlayer with an ESP32-S3 that plays audio itself. Deployed
ESP8266 devices keep running the V2 firmware unchanged.

Version 3 has **its own GitHub repository**, this one. The V2 repository stays, still maintained, for the V2
(ESP8266) devices, and its README points new builders here. Details in section 9.3.

In the plan below, "today" and "the current firmware" mean the V2 firmware in `et7ad/esp_athan`.

## 0. Implementation status (firmware 3.0.0, 2026-10-05)

Implemented: everything in sections 4–10. Where the build differs from the plan text, the build wins:

| Topic | Plan said | Implemented |
|---|---|---|
| Files | `firmware/athan_v3.yaml`, component `athan_audio` | `firmware/athan.yaml`, component `firmware/components/athan/` (`DEVELOPER.md`) |
| Radio defaults (7) | A "radio" list in the catalog and a **Reset Radio Stations** button | `docs/radio/stations.json` (exactly 10 stations) and a per-slot switch **Radio N follows project list** (on by default). As built, the list stays in memory (fetched at boot and every 6 hours), so changing a link there reaches every following clock within 6 hours. Off = the slot's own link (`Radio N own link`). The OLED shows the station's name from the list |
| Catalog (5) | Absolute URLs, a `radio` list | Lists `athan`, `fajr`, `tawashih`, `tick` only; a `url` may be relative to `docs/audio/`. Clocks re-read it every 12 h |
| Preview (6.1) | 20 s | Plays until stopped, Left/Right move on, or a choice is made. The selected entry plays from flash, not the internet. A sound list opens on the selected entry and plays it. Downloading the selected entry again does nothing |
| Location | Index persisted | The **key** is persisted (`selected_location_key`), so the Location list may be reordered or extended freely |
| Generator (9.2, 9.3) | One script writes the V3 yearly file and the V2 daily files | Every script here writes **only** the V3 yearly file (one positional list per day). V2 daily files are produced in the V2 repository with its own scripts. `make_yearly_json.py` converts years that exist only as V2 daily files |
| Built-in tones (4.1) | `audio_file` | `media_player: files:` from `firmware/sounds/click.mp3` and `volume.mp3` (V2's C3 and C2), added by the builder |
| Stand-in mark (9.2) | Shape open | A small hollow square, top right with the status marks (the timetable screen, 2026-10-08); "[estimated]" on the web page |
| Wi-Fi setup screen (8.1) | Text open | `Wi-Fi setup:` / `BT: press Select` (or `allowed`, `joining..`) / `Hotspot: on` or `soon`. On that screen a Select press only authorises Bluetooth |
| Radio menu (7) | Select plays or stops | Select plays or stops **and returns to the clock**. All ten slots are listed (an empty one says "No link here"). On the clock, Up plays the slot chosen last, or stops the radio |
| Buttons (3.1, 6.2) | Two buttons, Next and Select; a list menu | **One 5-way switch** (Up, Down, Left, Right, Select; owner's choice 2026-10-06). Clock screen: Left/Right = volume of what plays, Up = radio, Down = relay, Select = menu; Up/Down/Select stop the athan, tawashih, tick or a preview. The menu is two wheels (Up/Down rows, going round, with an Exit row; Left/Right items) in two panes, five rows by short name and icon on the left, the full title on the right (2026-10-09); Tick Window became the rows Tick From and Tick Until. Power-up: Select held = forget Wi-Fi, any direction held = unlock (README 1.3, CLAUDE.md "Keys and the menu") |
| USB-C (3.1, 3.4) | 16-pin with USB data; flashing and logs over the charging cable | **6-pin power-only USB-C** (owner's choice 2026-10-05, with 5.1 kΩ CC resistors). The first flash and serial logs go through J6, a populated 1×6 UART header (GND, IO0, EN, TXD0, RXD0, 3V3; jumper 1–2 = download mode) with a 3.3 V USB-serial adapter; the firmware logs on UART0. Later updates go over Wi-Fi |
| Empty slot | Download the default again at the next boot | Downloaded again automatically while online, at most every 30 min per slot (a missing default is not hammered) |

Menu rows as built (16): Radio, Athan, Fajr Athan, Tawashih (Random first), Pre-Fajr, Hourly Tick, Tick From,
Tick Until, Athan On/Off, Volume, Fajr Volume, Location, Clock, Update, Lock Buttons, Info. No Cancel item: Up from the first
row or Down from the last returns to the clock.

Still open: the sound files and their names in `docs/audio/catalog.json` (placeholders now), the F8 choice in
5.1, and everything in section 13.

The baseline is deliberately simple and efficient: no line-out jack, no RTC, no SD card. Everything else that came
up is collected in section 16 (Optional, for later) together with what it would take.

## 1. Goals

1. Remove the DFPlayer Mini and its "stuck until a power cycle" failure for good.
2. Internet radio on the device's own speaker, ten user-editable station slots.
3. Each on-device sound is one replaceable file: chosen from a suggested list on GitHub, or uploaded by the owner,
   always checked before it replaces the current one.
4. Wi-Fi setup over Bluetooth from a phone, the way commercial smart-home devices do it, with the hotspot kept as a
   second method so every phone can set it up (section 8).
5. HTTPS everywhere: prayer data, the audio list and firmware updates come straight from GitHub (no githack
   mirror); OTA updates come from GitHub Releases.
6. Keep every current feature: scheduled athan with the separate Fajr recording and Fajr volume, per-prayer on/off,
   hourly tick and tick window, the tawashih 25 min before Fajr with the relay (today's hidden Q option, renamed
   **Pre-Fajr Tawashih** and made visible: section 6.3), OLED and two-button menu, button lock,
   12 h clock, web page, Home Assistant API, optional display.
7. Keep the per-unit cost about where it is (≈ $6 today for ESP-12F + DFPlayer + SD card).
8. Prayer times stored a whole year at a time: once the clock is set, the device keeps calling the athan without
   internet for as long as it has power (section 9.2).

Non-goals: changing the prayer-time JSON contract (`prayertimes_specs.md`), the mosque list, or anything in the
ESP8266 firmware.

## 2. Why the DFPlayer goes

The DFPlayer is a second microcontroller the ESP cannot see into. The clone chips read the ESP8266 boot-ROM log on
GPIO1 as commands, choke on commands sent back to back, and only recover after a power cycle. The firmware cannot
tell when a track ends (`make_athan` assumes 5 minutes). It also cannot stream: its UART carries only commands, it
has no audio input, and it plays only from its own card.

In version 3 the ESP32-S3 decodes the audio and sends it digitally (I2S) to an amplifier chip. There is no second
processor to lock up, the firmware knows the real playback state, and the same path plays local files and network
streams.

## 3. Hardware

**Decided 2026-10-04: the bare ESP32-S3-WROOM-1-N16R8 module soldered on our own board**, like the ESP-12E today.
It is the cheapest and cleanest option; we design the USB-C and power ourselves, and the front side is SMD-assembled
by the PCB house. Sections 3.1–3.5 describe this build. Section 3.6 lists which ESP32 boards can run the design at
all (useful for prototyping).

### 3.1 Parts

| Part | Role | Price (LCSC qty 1, Oct 2026) |
|---|---|---|
| **ESP32-S3-WROOM-1-N16R8**, LCSC/JLCPCB **C2913202**: 16 MB flash, 8 MB PSRAM, dual-core 240 MHz, 2.4 GHz Wi-Fi + Bluetooth LE, PCB antenna on the module. Not the WROOM-1**U** (external antenna connector) | Wi-Fi, Bluetooth setup, decoding, all device logic | $5.19 (10+: $4.56, 100+: $3.64) |
| **MAX98357AETE+T**, LCSC/JLCPCB **C910544**, TQFN-16 3 × 3 mm | DAC + class-D amplifier in one chip: I2S in, 3.2 W into 4 Ω at 5 V, mono | $1.33 (10+: $1.16, 100+: $0.89) |
| **USB-C receptacle, 16-pin (USB 2.0 data)**, 5.1 kΩ from CC1 and from CC2 to GND, ESD protection on D+/D− (USBLC6-2SC6 or similar) | 5 V power from any charger (C-to-C included) and flashing/logs over the same cable | ≈ $0.30 |
| 3.3 V LDO, ≥ 600 mA (AMS1117-3.3 works from a solid 5 V rail) | ESP rail only; the amp runs from 5 V directly | — |
| Resistors and capacitors | Pull-ups, EN RC, decoupling, bulk | — |
| 2-pin terminal: speaker (4 Ω 3 W, same speaker as today) | Back side | — |
| 2-pin terminal: relay output (GPIO signal + GND, same as today, drives the external IoT relay) | Back side | — |
| 5-way switch (Up, Down, Left, Right, Select), 10 × 10 mm, 6-pin SMD | Back side, hand-soldered (HARDWARE.md 3.5) | — |
| Status LED + resistor | Back side | — |
| 4-pin OLED header (GND, VCC, SCL, SDA) | Back side; the SSD1306 module plugs in or is wired in the enclosure | — |
| Programming pads, **unpopulated**: GND, 3V3, EN, GPIO0, TX0 (GPIO43), RX0 (GPIO44) | Recovery only (section 3.4) | — |

Removed compared with the current board: DFPlayer Mini, microSD card, 3.5 mm AUX jack, the on-board display
footprint (the display becomes a header), the 6-pin power-only USB-C (replaced by the 16-pin data one), the
5-pin programming header, the speaker slide switch SW3 (the amp is shut down from firmware instead), and the
separate 5 V screw-terminal power input (USB-C only; see section 16 if a terminal is still wanted).

**Who makes the analog audio:** the MAX98357A. The ESP32-S3 has no DAC; it only sends digital audio. The DAC and
the power stage are both inside the MAX98357A. Its output drives a speaker directly and is not line level, which
is why a line-out jack would need its own DAC chip (section 16).

**Wi-Fi band:** the ESP32-S3 is 2.4 GHz only, as today. That suits this device (a 128 kbps stream is small,
2.4 GHz goes further through walls, home routers broadcast both bands). 5 GHz would mean the ESP32-C5, which is in
section 16.

### 3.2 Board layout

- **Front (top, SMD, assembled by the PCB house):** ESP32-S3 module, LDO, resistors and capacitors, MAX98357A,
  USB-C receptacle and its ESD part, the unpopulated programming pads.
- **Back (bottom):** the 5-way switch, relay terminal, speaker terminal, status LED, OLED header.
- Use through-hole parts on the back: they are soldered from the front, so the board needs only one-sided SMD
  assembly. SMD parts on both sides cost extra at assembly.
- The module's antenna goes at a board edge, with no copper on either layer under or around it, no back-side part
  under it, and the speaker magnet kept away from it.
- The MAX98357A (3 × 3 mm TQFN with exposed pad) needs reflow, so leave it to the assembly service. Keep the I2S
  traces short and away from the antenna.
- Both the module (C2913202) and the amp (C910544) are "Extended" parts at JLCPCB, which adds a small one-time
  setup fee per part per order. The module is moisture-sensitive (MSL 3), which the assembly house handles.
- Bulk capacitance near the amp: an SMD electrolytic or polymer cap, or several 22–47 µF ceramics, so nothing tall
  sits on the front.
- OLED modules disagree on header order (GND-VCC-SCL-SDA vs VCC-GND-SCL-SDA). Match the modules actually bought
  and print the order on the silkscreen.

### 3.3 Pin map (ESP32-S3-WROOM-1-N16R8; check against the module datasheet when drawing)

| Function | GPIO | Notes |
|---|---|---|
| I2S BCLK / LRCLK / DOUT → MAX98357A | 5 / 6 / 7 | |
| MAX98357A SD_MODE | 15 | Through 4.7 kΩ (changed 2026-10-06 from 560 kΩ; anything 1–47 kΩ): high = left channel only (the firmware sends the same mono samples in both I2S slots), low or floating (boot) = amp off, no idle hiss (`max98357a_amplifier.md` section 5) |
| I2C SDA / SCL → OLED header | 8 / 9 | 4.7 kΩ pull-ups on the board |
| 5-way switch Up / Down / Left / Right / Select | 14 / 10 / 21 / 47 / 11 | Internal pull-ups, common pin to GND (HARDWARE.md 3.5). Down and Select are the old Next and Select pins |
| Relay output | 12 | Series resistor, as today |
| Status LED | 13 | |
| USB D− / D+ | 19 / 20 | Native USB Serial/JTAG |

Do not use: GPIO0, 3, 45, 46 (boot straps; GPIO0 only on the recovery pads), 19/20 (USB), 26–32 (internal flash),
35–37 (octal PSRAM on R8 modules), 43/44 (UART0, recovery pads).

### 3.4 Programming

The USB-C port carries data, so flashing and logs need no programming header: the ESP32-S3's built-in USB
Serial/JTAG enters download mode on its own. The unpopulated pads exist only for recovery: if a bad firmware
crashes before USB comes up, hold GPIO0 to GND while resetting (EN) to force the ROM download mode. They cost
nothing and need no part fitted.

### 3.5 Amplifier and power

- The amplifier circuit copies Adafruit's MAX98357A board (product 3006), with SD_MODE on a GPIO and a gain jumper;
  full schematic, parts (which can be through-hole), gain advice and layout are in **`max98357a_amplifier.md`**.
- Gain: a 2 × 3 jumper header selects 3/6/9/12/15 dB; start at 9 dB (no jumper). At 5 V into 4 Ω the clean
  maximum is 2.5 W at 9, 12 and 15 dB alike; higher gain only clips sooner. Firmware volume is applied on top.
- Speaker wired straight to OUTP/OUTN, no output filter: the chip is filterless, and the speaker wires are about
  5 cm (Maxim recommends the EMI filter only above about 30 cm). The filter is in section 16 for later.
- 5 V 2 A USB-C supply. At full volume into 4 Ω the amp pulls close to 1 A in peaks; the S3 adds about 350 mA
  during Wi-Fi transmit peaks.
- Decoupling: 10 µF + 100 nF at the amp's VDD, ≈ 470 µF equivalent bulk on 5 V near the amp, 22 µF + 100 nF at the
  module's 3V3. EN: 10 kΩ pull-up + 1 µF to GND.

### 3.6 Which ESP32 boards work

The design needs an **ESP32-S3** (two cores and PSRAM for ESPHome's audio stack) with **8 MB PSRAM** (staging
buffer + stream buffers) and **16 MB flash** (two firmware slots + the 9.5 MB audio partition of 4.2).

| Board / module | Flash / PSRAM | Fits? |
|---|---|---|
| ESP32-S3-WROOM-1-N16R8 module (chosen), ESP32-S3-DevKitC-1 N16R8 (prototype, same module) | 16 MB / 8 MB | Yes |
| Seeed XIAO ESP32S3 **Plus** | 16 MB / 8 MB, 20 GPIO (11 edge + 9 rear pads) | Yes, but not chosen (section 14) |
| Seeed XIAO ESP32S3 (regular; for example Amazon B0DJ6NQFKX, 3-pack) | 8 MB / 8 MB, 11 GPIO | Audio only, not storage: after two firmware slots about 4 MB is left, so the slots would have to shrink to ≈ 1.2 MB each (5 min at 32 kbps). Fine for the breadboard prototype with smaller slots |
| ESP32-S3 SuperMini, Waveshare ESP32-S3-Zero and similar | 4 MB / 2 MB | No |
| Classic ESP32 (WROOM-32), ESP32-C3, ESP32-C6 | No or little PSRAM, C3/C6 single core | No |

## 4. On-device audio: one file per sound

### 4.1 What the device keeps

| Slot | Plays | Size limit | Duration limit |
|---|---|---|---|
| `athan` | Dhuhr, Asr, Maghrib, Isha | 3 MB | 5 min |
| `fajr` | Fajr | 3 MB | 5 min |
| `tawashih` | Pre-Fajr Tawashih, 25 min before Fajr (6.3; today a random pick from D1–D10) | 3 MB | 5 min |
| `tick` | Hourly tick | 0.4 MB | 1 min |

MB here means 1,000,000 bytes, the same unit Finder and Windows show, so a user can compare. The menu click and
the volume tone are tiny and never change; they are built into the firmware (`audio_file`).

There is no library, file numbering or choice index on the device. Each slot holds exactly one file plus a short
label (the name from the list, or the uploaded file's name), kept so the web page and the OLED can say which sound is
selected. Changing a sound means replacing that slot's file.

Format: MP3 (any bitrate and sample rate; ESPHome's resampler handles the rest). Mono, or stereo with the whole
sound in the left channel: the clock plays only the left channel (README 1.5). Other formats are
in section 16.

### 4.2 Flash layout

No filesystem. A raw data partition is split into four fixed regions, one per slot. Each region starts with a
4 KB header (magic, length, label, CRC) followed by the file. Playback memory-maps the region (`esp_partition_mmap`)
and hands it to the media player as an in-memory audio file, the same way firmware-embedded files are played. The
file is not copied into RAM.

Proposed partition table for 16 MB (0x1000000):

| Partition | Size | Holds |
|---|---|---|
| bootloader, table, NVS, otadata | 64 KB | as usual (NVS holds the settings and the ten radio URLs) |
| app0 / app1 | 2 × 3.54 MB (0x360000 each) | firmware, two slots for safe OTA |
| prayer | 128 KB (0x20000) | stored prayer-time years: 8 slots of 16 KB (section 9.2) |
| audio | 9.5 MB (0x910000) | athan, fajr, tawashih regions 0x2E0000 each (3,014,656 bytes ≥ 4 KB header + 3 MB), tick region 0x70000 (458,752 ≥ 4 KB + 0.4 MB) |

The four rows fill the 16 MB exactly. Measure the real firmware size on the prototype before fixing the table;
there is roughly 1.5 MB of slack per app slot.

### 4.3 Replacing a file (download from the list, or upload)

1. Receive the whole file into **PSRAM**, never straight into flash.
   - Download: if `Content-Length` is over the slot's limit, refuse before reading. Either way, count bytes while
     reading and abort as soon as the limit is passed.
   - Upload: the same, using the request's length and a running count.
2. Check it in PSRAM: it must parse as MP3 (skip an ID3v2 tag, then find valid frames) and the duration, summed
   from the frame headers (or read from a Xing/Info header), must be within the slot's limit.
3. Any failure (network error, too big, too long, not MP3, the user cancels): free the PSRAM buffer, show the
   reason, and leave the slot untouched. A partial download never reaches flash, so nothing needs cleaning up.
4. Only after every check passes: erase the slot's region, write the file, then write the header last. This takes
   tens of seconds; the OLED and the web page show progress.
5. Refuse to start a download while an athan is playing or another download is running.

Accepted risk: a power cut during step 4 leaves the slot without a valid header. The device then treats the slot
as empty (4.4) and downloads the list's default again at the next boot with internet. Making step 4 atomic costs a
fourth 3 MB region (section 16).

### 4.4 First boot and missing files

- A new device has empty slots. Once Wi-Fi is up, it downloads its prayer times first (about 10 KB), then entry 1 of
  each list in the catalog (section 5).
- If a slot is empty or invalid at playback time (first boot without internet, or after the power-cut case above),
  the device plays the built-in tone three times and logs it, so the prayer time is still marked audibly.

### 4.5 PSRAM budget (8 MB)

One download at a time: up to 3 MB staging buffer, plus the media player's reader buffers (48 KB per pipeline: ESPHome's 1 MB default starved the I2S speaker and made the router drop the clock at station starts, CLAUDE.md), plus
Bluetooth buffers when setup mode is on (section 8). Local playback is memory-mapped and uses no PSRAM for the file.

## 5. The suggested lists on GitHub

One catalog file in the V3 repository (9.3), for example `docs/audio/catalog.json`, read over HTTPS from
`https://raw.githubusercontent.com/et7ad/esp32_athan/main/docs/audio/catalog.json`:

```json
{
  "athan":    [ { "name": "Reciter 1", "url": "athan/01.mp3" } ],
  "fajr":     [ { "name": "Reciter 1", "url": "fajr/01.mp3" } ],
  "tawashih": [ { "name": "...", "url": "tawashih/01.mp3" } ],
  "tick":     [ { "name": "...", "url": "tick/01.mp3" } ]
}
```

(As built: relative URLs resolve against `docs/audio/`; the radio stations are a separate file, section 7.)

- Up to 10 entries per list. **Entry 1 is the default** (first boot, empty slot). No other indices exist.
- Names: plain ASCII, short enough for the OLED (about 12 characters at the menu font), and every character used
  must be in the font's `glyphs:` list.
- The device fetches the catalog at boot and when a menu or the audio page needs it, and keeps it in RAM only.
- The ESP8266 devices keep reading the daily `docs/athantimes/` files and `docs/timezones/` through githack;
  nothing there moves. Version 3 reads the new yearly files instead (9.2).

### 5.1 The audio library in the V3 repository (decided 2026-10-04)

All current recordings become public in the V3 repository, so any device can preview, stream or download them; owners can
still upload their own (6.1). Layout, committed under `docs/` (today's `SDCard_files/` stays gitignored):

| Folder | From | Entries |
|---|---|---|
| `docs/audio/athan/01.mp3` … `10.mp3` | A1–A10 | regular athans |
| `docs/audio/fajr/01.mp3` … `10.mp3` | F1–F10 | Fajr athans (`fajr/k` is usually the same reciter as `athan/k`) |
| `docs/audio/tawashih/01.mp3` … `10.mp3` | D1–D10 | Pre-Fajr Tawashih |
| `docs/audio/tick/01.mp3` … `10.mp3` | B1–B10 | hourly ticks |
| `docs/audio/catalog.json` | — | names and URLs (names still to be written: reciter names, ASCII) |

C2 (volume tone) and C3 (menu click) are built into the firmware instead. `Z_fallback_*` is no longer needed.

Every file in the library must already pass the device's checks. Measured on 2026-10-04:

| Problem | Files | Fix |
|---|---|---|
| Over 3 MB, length fine | A7, A8, A10, F1, F2, F3, F6, D7, D8, D10 (128–321 kbps) | Re-encode to mono 64 kbps: 5 min = 2.4 MB. The clock plays only the left channel anyway |
| Over 5 min | F8 (5:17, 5.07 MB, no silence to trim) | Owner choice: cut with a short fade-out at 5:00, speed up ≈ 6 %, or use another recording; then mono 64 kbps (5 min at its current 128 kbps would be 4.8 MB) |
| Over 0.4 MB (its 52 s is within the 1-minute limit) | B3 (1.67 MB, 256 kbps) | Re-encode to mono 48 kbps: 0.31 MB. At 64 kbps it would be 0.42 MB, just over; a full-minute tick must stay at or below ≈ 53 kbps |
| Fine as they are | the other 28 files | Leave alone (several are already 16–40 kbps; re-encoding would only lose quality) |

Re-encode recipe (strips tags and cover art, which the device does not need):
`ffmpeg -i in.mp3 -map 0:a -map_metadata -1 -ac 1 -b:a 64k out.mp3` (use `48k` for ticks).
The library then totals about 52 MB (85.6 MB today), well within GitHub's limits for a repo.

## 6. Choosing sounds: web page and device menu

### 6.1 Web: the audio page

ESPHome's select entities have fixed options at compile time, so they cannot show names from the catalog. The
custom component (section 10) therefore serves its own small page, for example `http://athan.local/audio`: plain
HTML forms with no JavaScript, and every check runs on the device. For each slot:

- Which sound is selected (label) and the download status (idle, downloading 40 %, writing, failed: too long, …).
- The ten catalog entries, each with **Preview** (streams the file from the internet for 20 s, nothing is stored)
  and **Download** (the replace flow of 4.3).
- **Upload your own**: file picker + Upload. Same checks; refused before replacing if it is over the size limit or
  over the duration limit.

The main ESPHome page keeps its entities (volume, switches, buttons) and adds text sensors for the four labels, the
download status, and the audio page's address.

### 6.2 Device menu

- **Athan**, **Fajr Athan**, **Tawashih**, **Hourly Tick**: Next steps through the catalog names, streaming a
  preview of each (as today); Select downloads the highlighted one with progress on the OLED; failures show the
  reason and keep the current file. Hourly Tick also has an **Off** entry: a persisted on/off replaces today's
  "None" choice.
- **Pre-Fajr** toggles the Pre-Fajr Tawashih on or off in place, like Clock (6.3). It replaces the Q item.
- New **Radio** item (section 7). Everything else stays: Athan On/Off, Tick Window, Location, Update, Volume,
  Fajr Volume, Clock, Lock Buttons, Info, Cancel.

### 6.3 Pre-Fajr Tawashih (today's hidden Q option, renamed and visible)

The behaviour stays exactly as today; only the name and its visibility change:

- When it is on, 25 minutes before Fajr the device switches the relay output on, plays the `tawashih` slot at the
  Fajr volume, and switches the relay off after 15 minutes. Off by default, as today.
- **Visible everywhere:** a web/Home Assistant switch **Pre-Fajr Tawashih** (template switch,
  `restore_mode: DISABLED`, its `lambda` mirroring the global), the **Pre-Fajr** menu item that toggles in place
  (OLED: `Pre-Fajr` on line 1, `ON` / `OFF` on line 2, since both on one line may not fit 128 px at the menu
  font), and the `tawashih` slot on the audio page (6.1) and in the menu (6.2). The web page's description text
  says what it does, including the relay.
- The ten-Select-press guard (`q_select_count`) goes away; it is a normal toggle now.
- Renames in the V3 yaml: `q_flag` → `prefajr_enabled` (persisted bool), `run_quyam` → `run_prefajr`,
  `quyam_next_hour`/`_minute`/`quyam_triggered` → `prefajr_next_hour`/`_minute`/`prefajr_triggered`. The 25 and
  15 minutes become substitutions (`prefajr_offset_min`, `prefajr_relay_min`) so they live in one place.

## 7. Internet radio

- **Ten slots.** As built (decided 2026-10-05), each slot has a persisted switch **Radio N follows project
  list** (on by default) and a persisted text entity **Radio N own link** (up to 255 characters).
  - A following slot plays station N of `docs/radio/stations.json` in this repository. The list is fetched again
    (as built: at boot and every 6 hours, kept in memory), so the project can move a station and every
    following clock picks it up.
  - A slot that does not follow plays its own link. Empty slots are allowed.
- Web page: the ten switches and link fields, **Play Radio**, **Stop Radio**, and a **Radio Station** select.
  There is no Reset button: switching a slot back to "follows project list" is the reset.
- Device menu: **Radio**. Next moves to the next slot that has something to play (empty ones are skipped). Select
  plays or stops it and returns to the clock. The OLED shows `Radio N` and the station's name from the list (or
  "own link").
- Streams play on the media pipeline; the athan, Pre-Fajr Tawashih, tick and tones use the announcement pipeline.
- **The athan pauses the radio, and the radio resumes when the athan ends** (decided 2026-10-04). The Pre-Fajr
  Tawashih does the same. A live stream cannot stay paused for minutes (the station drops the connection), so
  "resume" means: remember the slot, stop the stream, and start the same slot again after the athan.
- The hourly tick and the menu tones last seconds, so they play over the radio with the radio lowered (mixer
  ducking) instead of pausing it.
- Stop Audio, the buttons in normal mode, and the button-lock silence path stop the radio for good (no resume),
  including when they are pressed during an athan that paused it.
- Supported: direct MP3, Opus or FLAC stream URLs over HTTP or HTTPS (the mp3quran.net stations are 128 kbps MP3).
  Not supported: AAC-only and HLS (`.m3u8`) stations. `.m3u`/`.pls` links must be opened by hand to get the stream
  URL inside.
- If a stream drops (router reboot), retry a few times, then stop and show it on the OLED. Behaviour checked on the
  prototype.

## 8. Wi-Fi setup: Bluetooth first, hotspot as fallback

Two methods, both always built in (decided 2026-10-04). Bluetooth is the main, smoother path. The hotspot (today's
method) stays, so phones that cannot do Bluetooth setup, iPhones in particular, are never stuck.

### 8.1 When setup mode starts

- **New device** (no network saved at all): the hotspot and Bluetooth both start immediately at boot (confirmed in
  the ESPHome 2026.9 source, `WiFiComponent::start()`).
- **After "forget Wi-Fi"** (Select held at power-up; on V2 both buttons): the reset saves a dummy network, so this
  behaves like the next case: Bluetooth after `wifi_timeout` (15 s), the hotspot after `ap_timeout` (about 3 min).
  Either way both methods end up available, and whichever finishes first wins.
- **Saved network unreachable** (new router, changed password, or a router that is simply off): the device keeps
  retrying the saved network. Bluetooth setup starts after `wifi_timeout` (short, for example 15 s) and the hotspot
  after `ap_timeout` (about 3 min, so a brief router reboot does not open a hotspot). When the saved network comes
  back, the device reconnects and both stop.
- The OLED shows which methods are open (line 1 `Wi-Fi setup`, line 2 `Bluetooth`, later `BT + hotspot`; the
  hotspot name goes on the Info screen and in the README, it is too long for one line), and the status LED blinks
  the Improv states.
- Holding any of the four directions at power-up unlocks the buttons.

### 8.2 Method 1: Bluetooth (Improv)

- ESPHome `esp32_improv`, the open Improv standard over Bluetooth LE. The owner picks the device on the phone,
  chooses the network and types the password; the device joins and opens its own page (`next_url`, for example
  `http://{{ip_address}}`; check the supported placeholders at implementation).
- **Physical confirmation:** `authorizer` = the Select button. The OLED shows "Press Select to allow setup", the
  same "press the button on the device" step commercial devices use. It works even when the buttons are locked.
- **Which phones:**
  - Android, and Chrome or Edge on a computer: a setup page on the project's GitHub Pages site with the Improv
    "Connect" button (`improv-wifi-sdk` web component), or improv-wifi.com. No app needed.
  - Any phone with the Home Assistant Companion app: it discovers the device and provisions it.
  - iPhone without Home Assistant: Safari has no Web Bluetooth, so the setup page cannot reach the device. These
    owners use method 2.

### 8.3 Method 2: hotspot (captive portal, as today)

- `wifi: ap:` + `captive_portal:`, unchanged from the ESP8266 firmware: SSID `AthanFallbackHotspot`, password
  `athan404`. The phone joins it, the setup page opens by itself (or at `192.168.4.1`), and the owner picks the
  network and types the password.
- Works on every phone and computer with Wi-Fi.

### 8.4 RAM

ESPHome warns that the Bluetooth stack together with audio components can crash a device. Mitigations:

- `esp32_ble: use_psram: true` moves about 40 kB of Bluetooth buffers out of internal RAM.
- Bluetooth runs only while the device has no Wi-Fi (`ble.enable` 15 s after Wi-Fi went, `ble.disable` on
  connect) and is off in normal use.
- Streaming needs Wi-Fi, so Bluetooth and streaming never run at the same time. What can overlap in setup mode is
  Bluetooth + hotspot + a local athan at prayer time; that combination is on the prototype checklist.

## 9. Online services and prayer data

### 9.1 GitHub over HTTPS

- No githack mirror. The ESP32-S3 does TLS (ESP-IDF certificate bundle), so the device uses raw links on branch
  `main` of the new V3 repository (9.3):
  - `https://raw.githubusercontent.com/et7ad/esp32_athan/main/docs/athantimes/<key>/<year>.json` (yearly prayer
    times with the time zone inside, 9.2)
  - `https://raw.githubusercontent.com/et7ad/esp32_athan/main/docs/audio/catalog.json` and the audio files
- **Firmware updates from GitHub Releases.** Each release carries the OTA binary and a manifest (version, binary
  URL, MD5) as assets. The device reads
  `https://github.com/et7ad/esp32_athan/releases/latest/download/<manifest>`, which redirects to GitHub's file host
  (ESPHome's `http_request` follows redirects). Use ESPHome's `update:` component with the `http_request` platform,
  or keep the current Check/Install flow pointed at the manifest. The device menu and web buttons stay as today.
- **Separate from the ESP8266 by construction:** V3 binaries exist only on the new repository's Releases, and V2
  devices only read the old repository's `docs/firmwareinfo/latest.json` (9.3). That matters because both chips'
  images start with the same 0xE9 byte, so an ESP8266 must never be offered a version 3 binary. Version 3 gets its
  own version numbering.
- GitHub rate-limits unauthenticated raw downloads per IP. A device makes one prayer-times request a year plus the
  occasional catalog, preview or download, far below that; section 16 has a CDN fallback if it ever matters.

### 9.2 Prayer times: one file per year (decided 2026-10-04)

The device downloads a whole year of prayer times for its mosque once and keeps it in flash. After that, the
internet is only needed to set the clock after a power-up; the prayer times never need the network again that year.

**The yearly file** (new, next to the daily folders): `docs/athantimes/<key>/<year>.json`.

```json
{"v":1,"location":"davis","year":2026,"tz":"PST8PDT,M3.2.0,M11.1.0",
 "fields":["fajr","fajr_iqa","sunrise","doha","dhuhar","dhuhar_iqa","asr","asr_iqa","maghrib","maghrib_iqa","isha","isha_iqa"],
 "days":[
["06:06","06:31","07:24","07:44","12:14","12:24","14:39","14:49","16:57","17:12","18:16","18:31"],
...
]}
```

- One row per day; `days[0]` is 1 January; exactly 365 or 366 rows; columns in the order of `fields`.
- Times are true 24-hour `HH:MM` (`14:39`, not `02:39`). The daily files carry afternoon times in 12-hour form and
  today's firmware adds 12 hours on the device. The generator now does that once: Fajr, sunrise and Doha as written;
  Dhuhr +12 if the hour is below 9; Asr, Maghrib and Isha +12 if below 12; each iqama like its prayer.
- `tz` carries the POSIX time zone, so one download covers both. DST changes are computed on the device from that
  string, offline.
- Size: Davis 2026 measured at 36 KB with all 12 time fields; the device refuses anything over 100 KB.
- Generated by a new script (for example `scripts/make_yearly_json.py`) from the existing daily files, so every
  mosque and year already published gets its yearly file at once. The daily files stay in the old repository for
  the V2 devices (9.3).
- Checked on 2026-10-04 against all 11 mosque-years published today: after the conversion every day's adhan times are
  in order (0 problems). 27 days have an iqama published a few minutes before its adhan (for example Davis's fixed
  1:15 Dhuhr iqama on days the adhan is 1:16–1:20); the script warns about those and keeps them as published.
- The script also compares every adhan with the same date of the previous year (through UTC, as the stand-in below
  does) and warns about any difference over a few minutes. Real years differ by at most a minute, so this catches
  typos the ordering check misses. Example: Davis 2025 has Dhuhr at 12:50 and `1:00` (instead of 12:00) on 3 and
  4 December, and wrong Asr and Maghrib on the 4th; those dates are past, and 2026 and 2027 are clean.

#### On the device

- The `prayer` partition (128 KB, 4.2) holds 8 slots of 16 KB. A slot is a header (magic, location key, year,
  day count, time zone, CRC) plus a compact table: every time as minutes since midnight in 2 bytes,
  366 × 12 × 2 = 8.8 KB. A new year goes into a free or unused slot with its header written last, so a power cut
  while writing never damages the year in use.
- Download: into PSRAM (refused over 100 KB), parse, then check that `location` and `year` match what was asked,
  there are 365/366 rows, every value is strict `HH:MM`, and each day's adhan times are in order (Fajr < sunrise <
  Doha < Dhuhr < Asr < Maghrib < Isha). Iqama values are stored but not checked, since nothing is scheduled by them.
  Any failure keeps what is stored and retries later.
- It downloads only when:
  1. the selected mosque's current year is not stored (first boot, or a different mosque chosen);
  2. from 1 December, next year's file. "Not found" is the normal answer for a while: many mosques publish their
     timetable late, sometimes days into January. It is never shown as an error. The device checks once a day in
     December, then every 6 hours from 1 January until the file is stored; after that it is never fetched again;
  3. the web **Refresh Prayer Times** button forces a fresh copy of the current year (for when a mosque corrects
     its timetable).
  Otherwise a stored year is never re-checked.
- Every day at midnight and at boot, the day's row is read from the stored table (local date, day of year) and the
  schedule is computed exactly as today. No network involved.
- The web page and the Info screen show which years are stored (for example `davis 2026, 2027`).

#### Until the new year's file exists, last year's times stand in

From 1 January, while the new year is not stored, the device takes each day's times from the same calendar date
of the previous year (29 February uses 28 February). The athan keeps sounding on time while the mosque has not
published yet.

- **Why that is accurate:** on the published data (Davis, Woodland and masjid15 2026 vs 2027, Davis 2025 vs 2026),
  same-date adhan times differ by at most 1 minute between consecutive years (mean 0.2 min).
- **Daylight saving:** the change dates move each year (US 2026: 8 March and 1 November; 2027: 14 March and
  7 November), and on the dates in between a copied local time is an hour off (seen in the data on 8–13 March and
  1–6 November). So each time is carried over through UTC: last year's local time on that date → UTC with last
  year's offset → local time with this year's offset, both from the stored POSIX time zone. With that, the stand-in
  stays within a minute on every date.
- **No previous year stored either** (for example a brand-new device set up in early January): the device downloads
  the previous year's file once to use as the stand-in.
- **What the owner sees:** a small mark next to the next-prayer time on the OLED (drawn with primitives, like the
  padlock; its exact shape is picked at implementation), and on the web page "Using 2026 times until the 2027
  timetable is published". The README's owner section explains the mark. When the real file arrives, the device
  switches at once and recomputes the next prayer.
- Only with no stored year at all and no internet does the device have no times; the OLED then says so and keeps
  retrying.

#### Time

- After a power-up the clock comes from SNTP, as today, within seconds of Wi-Fi (SNTP is restarted when the network
  comes up). A software restart (update, Restart button) should keep it: ESP-IDF keeps the time in the RTC across
  software restarts (to confirm on the prototype). Once set it runs on the module's crystal (drift around a
  second a day) and is re-synced whenever the internet is there, so internet outages after that do not matter.
- After a power cut *with* no internet, the device has no time until the internet returns. The RTC in section 16
  removes that last dependency.

**Owner workflow:** run the script and publish each mosque's next-year files (the yearly file in the V3 repository,
the daily files in the old one, 9.3) as soon as the mosque publishes its timetable, whether that is before December
or some days into January. V3 devices pick it up within a day in December and within 6 hours from 1 January; until
then the stand-in covers it. V2 devices need the daily files by 1 January. As of 2026-10-04, `sclaramca` and
`sclaraalnoor` have data only through 2026; `davis`, `masjid15` and `woodland` already have 2027.

### 9.3 Two repositories (decided 2026-10-04)

Version 3 gets a new GitHub repository (this one); the V2 repository stays for the V2 devices, and both are maintained.

**The new repository** (`et7ad/esp32_athan`, chosen 2026-10-05):

- As built, it started as a fresh folder with only what V3 needs, not as a copy with history. It holds the V3 yaml
  and custom component, `docs/audio/` with the catalog, `docs/radio/`, the yearly prayer files, the scripts, and
  (to come) the V3 KiCad board and enclosure. The V3 firmware binaries go on its GitHub Releases.
- Gets its own README (V3 owners and builders) and its own CLAUDE.md (V3 architecture: no DFPlayer, NVS settings,
  slots, yearly files, HTTPS). This plan and `max98357a_amplifier.md` move there.
- V2-only material (the ESP8266 yaml, the DFPlayer SD-card script and its notes, `docs/firmwareinfo/latest.json`)
  can be removed from the copy, since it lives on in the old repository.

**The V2 repository (`et7ad/esp_athan`)** stays for V2 devices (ESP8266 + DFPlayer) and keeps being maintained:

- Firmware fixes for the V2 yaml, its OTA pointer `docs/firmwareinfo/latest.json`, and new prayer-time years.
- Deployed V2 devices have its githack URLs built in, so these paths must never move or disappear:
  `docs/athantimes/<key>/<year>/<DDD>.json`, `docs/timezones/<key>.json`, `docs/firmwareinfo/latest.json`.
- A note goes at the top of its README, for example: "Building a new clock? Use the version 3 repository:
  &lt;link&gt;. This repository exists to support existing V2 devices (ESP8266 + DFPlayer) and keeps receiving
  their prayer-time updates."

**Prayer data in both repositories:** V2 devices read the daily files from the old repository; V3 devices read the
yearly file from the new one. As built (owner's decision 2026-10-05), the scripts in the V3 repository write **only**
the yearly file, one positional list per day and no per-day files. The V2 daily files are produced in the V2
repository with its own scripts (`break_json.py` and friends). Each new timetable is therefore one run here and
one run there. `scripts/make_yearly_json.py` built the yearly files of every year already published from the V2
daily files, and can do so again for a year that only exists there.

**Mosque list:** each repository's firmware has its own list. A new mosque goes into the V3 list, and also into the
V2 list (with its daily files and time-zone file) if V2 devices there need it.

## 10. Firmware structure

### 10.1 Files

- `firmware/athan.yaml` (as built; the plan called it `athan_v3.yaml`): ESP32-S3, ESP-IDF framework (required by
  ESPHome's audio stack), PSRAM on (octal), 16 MB flash, the partition table of 4.2.
- One custom external component (as built: `firmware/components/athan/`, see `DEVELOPER.md`) for what ESPHome
  lacks:
  1. slot storage: raw regions with headers, read, erase/write, CRC, labels;
  2. downloader: HTTPS into PSRAM with the size limit;
  3. upload handler on ESPHome's web server, plus the `/audio` page;
  4. MP3 validation and duration check;
  5. playback: memory-map a slot, wrap it as an audio file, pass it to the media player's on-device file playback
     (verify that API on the current ESPHome version);
  6. catalog fetch and parse; status for text sensors and the OLED;
  7. yearly prayer times: download, checks, the `prayer` slots, and handing today's row to the yaml (9.2).

  The yaml stays the single place for behaviour (menus, schedule, web entities), as today.

### 10.2 Audio chain

`i2s_audio` → `speaker` (i2s_audio, MAX98357A) → `mixer` speaker (inputs: media, announcement) → `resampler` →
media player with a media pipeline (radio, previews) and an announcement pipeline (athan, tawashih, tick, tones).
MP3 decoder for the slots; MP3/Opus/FLAC for radio. The amp's SD_MODE pin is a GPIO output: on before playback,
off a few seconds after the player goes idle.

### 10.3 Mapping today's scripts

| Today (V2 `firmware/athan.yaml`) | Version 3 |
|---|---|
| `dfplayer:` + `uart:` | Removed |
| Boot: wait 3 s, two `stop`s, volume | Removed |
| `dfp_play` (click/volume tone) | Play the built-in tone on the announcement pipeline |
| `make_athan` (5 min LED timer) | Play slot `athan` or `fajr` (`current_athan_prayer_index == 0`); `athan_playing`, LED and relay follow the real player state |
| `run_quyam` + `q_flag` (random D file, relay 15 min, switched on by 10 Select presses) | `run_prefajr` + `prefajr_enabled`: play slot `tawashih` at the Fajr volume, same relay timing; a normal visible toggle (6.3) |
| hourly tick | Play slot `tick` if tick is on and inside the window |
| `silence_audio` | Stop both pipelines |
| `apply_volume` / `apply_fajr_volume` | Player volume 0.0–1.0; Fajr level for the Fajr athan and the tawashih, then restore, as now |
| `web_preview` (20 s) | Stream the catalog URL until stopped or the next entry, nothing stored |
| `athan_file_index`, `fajr_athan_choice`, `htick_file_index` | Removed (no index); `htick_enabled` (bool) added |
| `dfp_recover`, SD substitutions, `Z_fallback_*` | Removed |
| `wifi: ap:` + `captive_portal` | Kept as the fallback method; `esp32_improv` (Bluetooth) added as the first method (section 8) |
| githack URLs, custom `latest.json` check | raw HTTPS + GitHub Releases (section 9) |
| `load_prayer_times` (daily HTTP fetch of `DDD.json`, +12 PM fix-ups on the device), `refresh_prayer_times_if_needed` | Read today's row from the stored year; downloads only per 9.2; the +12 fix-ups move to the generator script |
| `change_location_handler` (fetches `timezones/<key>.json`) | Downloads the new mosque's yearly file, which carries the time zone |
| persisted `prayer_hours` / `prayer_minutes` / `prayer_times_day` / `prayer_times_year` | Not persisted; the `prayer` partition is the store |
| `web_refresh_times` | Forces a fresh download of the current year (9.2) |

Everything else ports with new pins: schedule and next-prayer logic, menus and `ui_mode` (renumbered
for the new items), web entities and `sync_web_state`, button lock, 12 h rendering, display watchdog. The generic
ESPHome rules still hold: template switches keep `restore_mode: DISABLED`, and nothing touches the display or audio
from a trigger that can fire during setup. Settings live in NVS keyed by id, so the ESP8266's 128-word store and
positional-slot rules in the V2 `CLAUDE.md` do not apply to this yaml. RAM is no longer tight (512 KB SRAM + 8 MB PSRAM);
keeping explicit font `glyphs:` lists is still fine.

## 11. Cost per unit (parts that change)

| | Today | Version 3 |
|---|---|---|
| MCU | ESP-12F ≈ $2 | ESP32-S3-WROOM-1-N16R8 $5.19 (100+: $3.64) |
| Audio | DFPlayer clone ≈ $1–2 + microSD card ≈ $2–3 | MAX98357A $1.33 (100+: $0.89) |
| USB | power-only USB-C | 16-pin USB-C + ESD ≈ $0.30 |
| **Total** | **≈ $6** | **≈ $6.80 each at qty 1, ≈ $4.80 at 100+** (plus JLCPCB's one-time Extended-part fees) |

## 12. Documentation to update when version 3 lands

In the new V3 repository (9.3):

- README, rewritten for V3: the owner section (the two Wi-Fi setup methods, with "iPhone: use the hotspot"
  spelled out; the audio page; radio; upload limits; Pre-Fajr Tawashih; what the OLED's stand-in mark means, 9.2),
  and the data section (yearly files, the generator script, publishing each new year as soon as the mosque does).
- CLAUDE.md, rewritten for V3: new yaml and component, partition table, no DFPlayer, NVS settings, HTTPS URLs,
  update channel, yearly prayer files.
- DEVELOPER.md, plus HARDWARE.md for the V3 board (wiring, BOM, PCB and enclosure instructions in one file).
- `prayertimes_specs.md`: the yearly file (layout, true 24-hour times, `tz`, the 100 KB limit). Done 2026-10-05,
  together with README, CLAUDE.md, DEVELOPER.md and HARDWARE.md.

In the V2 repository: the README note pointing new builders to the V3 repository (9.3). Its daily files keep
coming from its own scripts (section 9.3 as built).

## 13. Prototype and acceptance checklist

Breadboard: **ESP32-S3-DevKitC-1 N16R8** (≈ €6–11; it carries the same ESP32-S3-WROOM-1-N16R8 module as the final
board, so the firmware and partition table carry over unchanged) + a **MAX98357A breakout** (Adafruit 3006, $5.95,
or a clone ≈ $3) + the current speaker, OLED and the 5-way switch. A regular XIAO ESP32S3 (8 MB flash) also works for
everything below except the full 3 MB slot sizes; shrink the slots in its partition table. Its 5V pin is USB VBUS
directly (Seeed schematic v1.2), so the amp breakout can take its 5 V from there.

1. Firmware size measured; partition table of 4.2 confirmed or adjusted.
2. Wi-Fi setup, both methods:
   - Bluetooth from Android Chrome (setup page) and from the HA app; the Select-button confirmation works;
     Bluetooth turns off after joining.
   - The hotspot from an iPhone; it appears after `ap_timeout`.
   - A new device and a device whose saved network vanished both reach setup mode; when the saved network
     returns, the device reconnects by itself.
   - Free internal heap checked with Bluetooth + hotspot on and a local athan playing.
3. Each slot downloads from the catalog; a slot is unchanged after: pulling the network mid-download, a file over
   the size limit (3 MB, tick 0.4 MB), a file over the duration limit (5 min, tick 1 min), a non-MP3 file. The OLED
   and the page show the reason.
4. Upload from the audio page with the same four failure cases.
5. Power cut during the flash write → the slot is treated as empty → the tone plays at prayer time → the default is
   downloaded again at the next boot.
6. Athan, Fajr athan, tawashih and tick play from the memory-mapped slots at 10 %…100 % volume; no hiss when idle
   with the amp shut down. Pre-Fajr Tawashih toggled from the web, from HA and from the menu: it fires 25 min before
   Fajr with the relay on for 15 min.
7. Radio: an mp3quran stream for an hour without dropouts; empty slots skipped; a following slot picks up a link
   changed in `docs/radio/stations.json`; an own link plays; behaviour after a router reboot is known.
8. Radio playing: a scheduled athan pauses it and the same station comes back when the athan ends; the Pre-Fajr
   Tawashih does the same; Stop during the athan leaves the radio off; an hourly tick plays over the lowered radio.
9. Web page, HA API, OLED and the switch respond while a stream plays; heap and PSRAM are stable over hours.
    The 5-way switch: each direction does what its name says as the owner faces the clock (else swap the pins in
    the yaml); every menu row works from Up/Down/Left/Right/Select; quick browsing never restarts the board;
    Left/Right change the volume of a playing athan and radio without stopping them; Up toggles the radio, Down
    the relay; both power-up gestures work; the timetable and the menu's titles and captions (Tiny5 pixel font) and
    the menu's icons are readable on the real OLED; the menu goes round and Exit returns with Select, Left or Right.
10. OTA from a GitHub Release (redirected asset URL) works; an ESP8266 device does not see it.
11. 5 V current at full volume measured; no brownout resets; no audible Wi-Fi buzz.
12. Prayer times: the generator script builds a yearly file for every published year, and they pass the device's checks.
    After the clock is set, unplugging the router for two days does not stop a single athan. Choosing another mosque
    downloads its year. With the clock set to 1 December the next year is fetched; to 1 January it is used. With
    no next-year file on the server, "not found" shows no error; from 1 January the stand-in runs (marker on the
    OLED, note on the web page) and the athan plays; publishing the file switches the device over within 6 hours.
    Stand-in dates inside a DST window (for example 10 March) come out right, not an hour off. A brand-new device in
    early January with no stored year fetches the previous year for the stand-in. A broken file (wrong year, a
    missing day, times out of order) is refused and the stored year stays. A power cut with no internet shows
    "no time" and recovers by itself when the internet returns.

## 14. Alternatives considered and rejected

| Option | Why not |
|---|---|
| Ready-made ESP32-S3 audio board (Waveshare ESP32-S3-AUDIO-Board ≈ $16) | Fine for prototyping; larger, carries mics/LEDs this device does not need, costs more than the custom board |
| M5Stack Atom VoiceS3R (≈ £14) | Tiny speaker, 8 MB flash, no room for the OLED and buttons |
| Linux board (Pi Zero 2 W, Orange Pi Zero 2W) + I2S amp | Plays everything, but boots in 26–54 s, the SD card can corrupt on power cuts, full rewrite |
| Wi-Fi streamer module (Arylic Up2Stream Mini, $39 without amp) | Closed firmware, phone-app setup, two Wi-Fi devices, ~6× the cost |
| ESP8266 + VS1053 decoder | ESP8266 RAM already exhausted, no practical HTTPS, still needs SD and an amp |
| Raspberry Pi Pico 2 W + BackgroundAudio | No ESPHome audio: full rewrite |
| Other serial MP3 modules (JQ6500, WT2003…) | Same class as the DFPlayer: no streaming |
| ESP32-C3/C6, classic ESP32 | No or limited PSRAM, single core (C3/C6); ESPHome audio targets the S3 with PSRAM |
| XIAO ESP32S3 Plus soldered onto our board instead of the bare module | Simpler board (Seeed did USB-C and power, hand-solderable with an amp breakout), but costs more per unit and needs a stick-on antenna on a U.FL cable; owner chose the bare module (2026-10-04) |
| Filesystem (LittleFS) for the slots | Needs a filesystem component and a file-reading media source; fixed raw regions are simpler and play without copying |

## 15. Decisions (2026-10-04)

No open questions remain. The owner decided:

1. Board: the bare ESP32-S3-WROOM-1-N16R8 module on our own board, SMD-assembled (section 3).
2. Wi-Fi setup: both Bluetooth and the hotspot (section 8).
3. The former Q option is visible everywhere and named **Pre-Fajr Tawashih** (6.3).
4. Hourly tick: at most 0.4 MB and 1 minute (4.1).
5. The athan pauses the radio, which resumes afterwards (section 7).
6. All current recordings go public in the V3 repository under `docs/audio/` for preview, streaming and download; owners can
   also upload their own (5.1).
7. Prayer times come as one file per mosque per year (≤ 100 KB), downloaded once and stored; the internet is then
   only needed for the clock (9.2). Next year's file is looked for from 1 December, may legitimately appear only
   days into January, and last year's times (carried over through the time zone) stand in until it does.
8. Version 3 lives in a new GitHub repository (this one, `et7ad/esp32_athan`); the V2 repository stays and is
   maintained for the V2 devices, with a README note pointing new builders to V3 (9.3).

Still to do: names for the catalog; the F8 choice in 5.1. (Repository name: `et7ad/esp32_athan`, 2026-10-05.)

## 16. Optional, for later

Each item is independent of the others; none is needed for the baseline.

| Idea | What it gives | What it takes |
|---|---|---|
| **5 GHz Wi-Fi: ESP32-C5** (ESP32-C5-WROOM-1-N16R8, dual-band Wi-Fi 6, one band at a time) | Works on 5 GHz-only or crowded 2.4 GHz networks | Single RISC-V core and 384 KB SRAM (S3: two cores, 512 KB). ESPHome supports the C5 on ESP-IDF, but no report found of its audio player on a C5. Run checklist 13 on a C5 dev board; new pin map; still Bluetooth LE for setup |
| **Speaker EMI filter** | Less radio interference if the speaker ever sits on longer wires (Maxim: above about 30 cm), or if the prototype shows Wi-Fi or radio trouble at full volume | A ferrite bead (Murata BLM18SG331TN1D, ≥ 1 A) in series with each output and 680 pF C0G to GND at the terminal; details in `max98357a_amplifier.md` section 8 |
| **RTC** (PCF85063A + CR1220 or supercap) | With the year's prayer times stored (9.2), the clock is the only thing that still needs internet after a power cut; an RTC makes the device fully offline | ≈ $1, on the I2C bus; ESPHome RTC time platform; sync from SNTP, read at boot |
| **3.5 mm line out** | Feed an external speaker or amp | PCM5102A DAC on the second I2S port + jack; a second `speaker` in the chain |
| **Atomic slot replacement** | No empty-slot window if power fails while writing | A fourth 3 MB "spare" region: write the new file into the spare, then swap which region a slot uses (tiny map in NVS). App slots shrink to ≈ 1.9 MB each, so it needs the firmware measured first |
| **Built-in fallback athan** | A real athan, not a tone, when a slot is empty | A short low-bitrate athan in the firmware via `audio_file` (≈ 0.5 MB at 16–24 kbps mono); costs app-slot space twice |
| **Factory audio image** | New devices ship with the default sounds, no first download | Build the four regions + headers on a PC (small script), flash them with esptool at the partition offset together with the firmware |
| **Browser installer** (ESP Web Tools on the GitHub Pages site) | Flash a new device and set Wi-Fi from Chrome over USB, no ESPHome install | `improv_serial` in the yaml + a manifest and page under `docs/` |
| **More upload formats** (Opus, FLAC, WAV) | Owners can upload what they have | Duration parsing per format; decoders already exist in ESPHome |
| **Names for own radio links** | OLED shows a name for a slot that plays its own link (following slots already show the list's name) | One more text entity per slot, or a "name, then URL" field format |
| **AAC / HLS stations** | Stations that are not MP3 | Through Home Assistant's transcoding proxy when HA is used; natively it would need a different audio library (ESP32-audioI2S, Arduino, not ESPHome) |
| **Bigger local library** (microSD) | Many recordings offline | SDMMC socket + `esphome_sd_card` + a custom media source; drops the "one file per slot" simplicity |
| **CDN fallback for GitHub** (jsDelivr) | Keeps working if raw.githubusercontent.com rate-limits or is blocked | Second base URL tried after a failure; jsDelivr serves GitHub repos over HTTPS |
| **5 V screw terminal input** | Hard-wired installations | Terminal + reverse-polarity protection in parallel with USB-C VBUS |
| **Hardware speaker mute switch** | A mute that works without firmware | Slide switch in series with the speaker, as today |
| **Louder audio** | Big rooms, small mosques | TAS5805M-class amp (needs a 12–20 V supply) instead of the MAX98357A |
| **32 MB flash** (ESP32-S3-WROOM-2-N32R8V) | Room for more slots or atomic replacement without shrinking the app | Octal flash; less proven with ESPHome |

## Sources

- ESPHome: [Speaker Audio Media Player](https://esphome.io/components/media_player/speaker/),
  [Speaker Source Media Player](https://esphome.io/components/media_player/speaker_source/),
  [Audio File](https://esphome.io/components/audio_file/),
  [Audio HTTP media source](https://esphome.io/components/media_source/audio_http/),
  [Improv via BLE](https://esphome.io/components/esp32_improv/), [ESP32 BLE](https://esphome.io/components/esp32_ble/)
- Improv on the web: [improv-wifi sdk-js](https://github.com/improv-wifi/sdk-js) (Web Bluetooth: Chrome/Edge on
  desktop and Android, no iOS)
- Module: [ESP32-S3-WROOM-1-N16R8 at LCSC (C2913202)](https://www.lcsc.com/product-detail/C2913202.html),
  [same at JLCPCB](https://jlcpcb.com/partdetail/3198300-ESP32_S3_WROOM_1N16R8/C2913202),
  [ESP32-S3-WROOM-1/1U datasheet v1.8](https://documentation.espressif.com/esp32-s3-wroom-1_wroom-1u_datasheet_en.pdf)
- Amplifier: [MAX98357AETE+T at LCSC (C910544)](https://www.lcsc.com/product-detail/C910544.html),
  [same at JLCPCB](https://jlcpcb.com/partdetail/MAX98357AETE+T/C910544)
- Prototype: [ESP32-S3-DevKitC-1 (Espressif docs)](https://docs.espressif.com/projects/esp-dev-kits/en/latest/esp32s3/esp32-s3-devkitc-1/),
  [Adafruit MAX98357A breakout (3006)](https://www.adafruit.com/product/3006)
- 5 GHz: [ESP32-C5](https://www.espressif.com/en/products/socs/esp32-c5),
  [ESP32-C5-WROOM-1 datasheet](https://documentation.espressif.com/esp32-c5-wroom-1_wroom-1u_datasheet_en.html),
  [ESP32-C5 vs S3](https://jrattechworks.com/esp32-c5-explained/),
  [ESP32-S31 (2.4 GHz only)](https://www.i-programmer.info/news/91-hardware/18785-new-esp32-s31-super-dual-risc-v-with-wifi-6.html)
- Other: [esphome_sd_card](https://github.com/n-serrette/esphome_sd_card),
  [ESP32-audioI2S](https://github.com/schreibfaul1/ESP32-audioI2S),
  [Waveshare ESP32-S3-AUDIO-Board](https://docs.waveshare.com/ESP32-S3-AUDIO-Board),
  [mp3quran stream format](https://radio.dubbeh.net/stations/mp3quran-main-2682),
  [Pi Zero 2 boot times](https://community.volumio.com/t/volumio-on-the-raspberry-pi-zero-2/50650?page=4),
  [Arylic Up2Stream Mini](https://arylic.com/products/up2stream-miniv2-receiver-board)

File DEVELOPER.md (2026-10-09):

# Developer notes (version 3 firmware)

How the firmware is put together, for anyone changing it. Owner-facing behaviour is in `README.md`, the design
reasoning in `version3_planning.md`, and the short list of rules in `CLAUDE.md`.

## 1. Files

| Path | What |
|---|---|
| `firmware/athan.yaml` | All behaviour: entities, menus, schedule, OLED, scripts, intervals (ESPHome + inline C++ lambdas) |
| `firmware/partitions.csv` | 16 MB layout: nvs, otadata, app0/app1 (0x360000 each), `prayer` (0x41, 128 KB), `audio` (0x40, 0x910000) |
| `firmware/components/athan/__init__.py` | Component schema: `media_player`, `media_speaker` and `announcement_speaker` (the two resamplers, for clean starts and format checks), `time_id`, `data_url`, `radio_urls` (list of `text` ids). Requests the MP3 decoder, the certificate bundle, `esp_http_client` and `esp-tls` |
| `athan.h/.cpp` | `AthanComponent`, the worker task, `AudioWebHandler` (the `/audio` page) |
| `audio_slots.h/.cpp` | The four stored sounds |
| `prayer_store.h/.cpp` | Yearly file parser + the stored years |
| `tz_posix.h/.cpp` | POSIX TZ parser, offset/UTC conversion, calendar helpers (no ESPHome dependency) |
| `mp3_check.h/.cpp` | MP3 validity and duration (no ESPHome dependency) |
| `firmware/tests/` | `run_tests.sh` (host unit tests), `syntax_check.sh` (type check), `idf_stubs/` (SDK stand-ins) |
| `firmware/sounds/` | `click.mp3`, `volume.mp3`: built-in tones (`media_player: files:`), added by the builder |

## 2. Boot

1. ESPHome setup by priority. `AthanComponent::setup()` (priority `AFTER_WIFI`) does the following:
   1. Maps the audio regions and verifies each header and data CRC (`AudioSlots::begin`).
   2. Reads the prayer slot headers (`PrayerStore::begin`).
   3. Starts the worker task (`athan_worker`, 10 KB internal stack, priority 1: the same as ESPHome's main loop and
      the audio pipeline's tasks, which a TLS handshake at a higher priority held off for hundreds of ms).
   4. Registers the `/audio` handler on `web_server_base`.
2. `esphome: on_boot` (priority -100):
   1. Copies `volume_level` into `fajr_volume_level` the first time (when it is -1).
   2. Calls `set_location(selected_location_key)`.
   3. Adds the menu's rows (`menu_setup`).
   4. Handles the two power-up gestures of the 5-way switch: Select held forgets Wi-Fi and restarts; any
      direction held unlocks the buttons.
   5. Applies the volume and draws the screen.
3. `AthanComponent::loop()` runs a 1 s tick:
   1. Fetches the catalog and the station list when due.
   2. Downloads the default into an empty slot (catalog entry 0; per slot at most every 30 min). While the location
      has no prayer times at all, this waits until their download has run once (`prayer_first_()`, at most 90 s after
      the network came up): a year of times is about 10 KB, a sound 3 MB plus a flash erase, on the same worker.
   3. Runs `prayer_tick_()` (its job goes to the front of the queue while no times are loaded) and `radio_tick_()`.
   `net_watch_()` restarts SNTP when the network comes up and the clock has no time: ESPHome starts SNTP once at
   boot, and each request made without a network doubles lwIP's retry wait (15 s up to 150 s).
4. The yaml's 1 s interval watches `schedule_version()` and reruns `load_today` when it changes (new day, new
   data, new location).

Nothing in a setup-time trigger may draw or play (`CLAUDE.md`). Template switches use `restore_mode: DISABLED`.

## 3. Component API (called from yaml lambdas as `id(athan_core).…`)

| Method | Use |
|---|---|
| `slot_valid(s)`, `slot_label(s)` | Slot 0 athan, 1 fajr, 2 tawashih, 3 tick |
| `play_slot(s)` → bool | Plays the mapped file on the announcement pipeline, once that pipeline has stopped (clean start). False if the slot is empty or being rewritten (the yaml then plays three click tones) |
| `play_tone(file)`, `stop_announcements()` | The only way the yaml starts or stops the announcement pipeline: a tone waits for the sound before it to stop; never over the athan, tawashih or tick |
| `set_hard_stop_callback(cb)` | The yaml's `hard_mute`, called when browsing leaves a playing preview, by `stop_preview()`, and for the `/audio` page's Stop |
| `set_wifi_bg_only(on)` (yaml `wifi_bg_only:`) | Wi-Fi 802.11b/g only (`esp_wifi_set_protocol`), set in `setup()` during ESPHome's first scan and at every `WIFI_EVENT_STA_START` |
| `set_wifi_low_latency(on)` | Wi-Fi modem sleep off (`on`) or back on. Only while Bluetooth is off: the yaml calls it after `ble.disable` has finished and before `ble.enable` (`ble_when_offline`, 15 s after Wi-Fi went) |
| `slot_playing()` | True from `play_slot()` until the player leaves `ANNOUNCING` (or 5 s if it never got there) |
| `download_from_catalog(list, entry)` | Downloads → checks → writes; progress in `sound_status()`. The selected entry is never downloaded again ("already selected"); downloading another entry first fetches it anew |
| `selected_entry(list)` | Index of the list entry (the selected one) whose link matches the slot's stored source CRC (version 1 headers: the label), -1 for an upload or an unlisted sound |
| `sound_busy()`, `sound_status()` | One download/upload at a time |
| `fetch_catalog()`, `catalog_ready()`, `catalog_size(l)`, `catalog_name(l, e)` | Suggested lists |
| `has_custom(list)` | The slot holds a sound that is not a list entry: an upload (source 0), or a download the loaded list no longer has. Shown as "Custom" in the menu and on `/audio` |
| `menu_size(l, off)`, `menu_item(l, off, i)`, `menu_index(l, off, item)` | The OLED sound list: `MENU_OFF` (tick only), `MENU_RANDOM` (tawashih, first), `MENU_CUSTOM` (while `has_custom`), then the entries. `MENU_NONE` for an index with nothing there |
| `tawashih_random()`, `set_tawashih_random(on)` | The Random tawashih (default, saved as a preference). On frees the stored tawashih (`CLEAR_SLOT` once nothing plays from it); a download or upload started after the choice turns it off |
| `play_random_tawashih()`, `tawashih_streaming()`, `stop_tawashih()` | Pre-Fajr with Random: streams a random entry (not the last one), one retry with another entry if it fails at once; false without internet or list |
| `has_stored_times()` | The location has stored prayer times: the timetable shows the last day's times and the next prayer (saved globals) struck through until the clock is set |
| `request_preview(l, item, ms)` | How the menu and `/audio` start previews: stops the current preview at once (one STOP), starts the new one (`preview_catalog` or `preview_stored`) after `ms` without another request. Menu Left/Right use 500 ms, reaching a sound row 800 ms, `/audio` 300 ms. Keeps fast browsing to one stream and a few media commands (CLAUDE.md, "Never send media player commands in bursts") |
| `preview_stored(list)` | Plays the stored sound from flash as a preview (the Custom item; `/audio/preview?entry=-1`) |
| `preview_catalog(l, e)` | Nothing stored. The selected entry plays from flash (`play_slot`, marked as a preview); any other streams on the media pipeline. Either replaces the radio. Refused while the athan, tawashih or tick plays |
| `stop_media()` | Stops the media pipeline (preview or radio) and a preview playing from flash, never the athan or the tick. Drops a stream still waiting to start |
| `stop_preview()` | Stops a preview (and one still waiting for its pause) silently (`hard_stop_cb`); nothing else. The radio plays on unless a preview had replaced it. The menu calls it when it leaves a sound row |
| `menu()` | The OLED menu (`Menu`, `menu.h`): `open()`, `close()`, `key(k)`, `is_open()`, `add_row(row)`, `set_on_close(cb)`. Main loop only |
| `radio_play(slot, subscribed)`, `radio_stop()`, `radio_active()` (-1 or slot) | Radio |
| `station_available(slot, subscribed)`, `station_name(slot)`, `own_url(slot)`, `radio_status()` | Radio menu/web |
| `set_location(key)`, `location()` | Changing the key resets the fetch timers and bumps `schedule_version()` |
| `schedule_version()` | Changes whenever today's times may have changed |
| `today_times(h[7], m[7])` → bool | Fajr, Sunrise, Doha, Dhuhr, Asr, Maghrib, Isha for today (local), stand-in included |
| `times_standin()` | Today's times come from last year |
| `refresh_prayer_times()`, `prayer_status()` | Force a fresh current-year download; status line |
| `web_action`, `upload_begin/data/end`, `render_audio_page` | Used by `AudioWebHandler` only |
| `wifi_drop_count()`, `wifi_drops_text()` | Wi-Fi connections lost since start, and the last three with time, ESP-IDF reason and RSSI (an `esp_event` handler on `WIFI_EVENT_STA_DISCONNECTED` keeps the reason). The web page's Wi-Fi Drops |

Also from lambdas: `athan::draw_menu(display, menu, {large, medium, small})` (`menu_view.h`) draws the open menu.

## 4. Threading

- **Main loop:** the yaml, `loop()`, the media player calls, entity publishing, the stored-sound map.
- **Worker task:** a FIFO of `Job`s (`CATALOG`, `STATIONS`, `STATION_PLAY`, `DOWNLOAD_URL`, `COMMIT_BUFFER`,
  `PRAYER_YEAR`). It does HTTPS (`http_get_`: crt bundle, manual redirect loop up to 5 hops, 20 s timeout, size
  limit before and during the read, PSRAM buffer), JSON parsing and flash erase/write. Results come back with
  `defer()`.
- **httpd task:** `AudioWebHandler` renders the page (a `PsramString`, about 14 KB) from copies taken under one
  `mutex_` lock: the catalog and `slot_view_`, a snapshot of each slot (name, length, selected entry, Custom) that
  only the main loop refreshes (`refresh_slot_view_()`: boot, catalog load, before and after a rewrite). It queues
  download/preview/stop in `web_actions_` (`loop()` looks only when `web_actions_pending_` is set). Uploads are
  appended into a PSRAM buffer under `mutex_`, and `upload_end()` queues `COMMIT_BUFFER`.
- **Slot rewrite handshake:** after the file passes every check, the worker `defer`s a request to the main loop
  to `invalidate()` the slot. The main loop refuses if that slot is playing. The worker waits up to 10 s on a
  semaphore owned by a `shared_ptr<Handshake>`, so a late answer can't touch a dead stack frame. Then it writes,
  and `defer`s `reload()`.

`mutex_` guards the lists, the status strings, `web_actions_` and the upload buffer. `catalog_ready_`,
`stations_ready_`, `sound_busy_` and the pending flags are atomics. Retry deadlines are `uint64_t` from
`millis_64()`.

## 5. Stored sounds

**Regions** (inside the `audio` partition):

| Slot | Offset | Size | File limit | Duration limit |
|---|---|---|---|---|
| 0 athan | 0x000000 | 0x2E0000 | 3,000,000 B | 5 min |
| 1 fajr | 0x2E0000 | 0x2E0000 | 3,000,000 B | 5 min |
| 2 tawashih | 0x5C0000 | 0x2E0000 | 3,000,000 B | 5 min |
| 3 tick | 0x8A0000 | 0x070000 | 400,000 B | 1 min |

**Header** (first 4 KB sector of the region): `magic "ATH1"`, `version 2`, `length`, `data_crc`, `duration_ms`,
`label[64]`, `source_crc` (CRC-32 of the download link, never 0; 0 for an upload), `header_crc` (CRC-32 of the
fields before it). A version 1 header (no source) is still read: its `header_crc` sits where `source_crc` is now, and such a sound is matched to the list by its
label. The MP3 follows at +4 KB. `begin()` and `reload()`
check both CRCs, then memory-map the region (`esp_partition_mmap`) and wrap it in an `audio::AudioFile`
(`audio::AudioFileType::MP3`), which `play_slot()` hands to `SpeakerMediaPlayer::play_file(file, announcement=true)`.
They also run `mp3_scan()` over the file: the `AudioFile` starts at its first chained frame (a tag or junk before
it could give ESPHome's decoder a false header, whose sample rate it would keep), and the real sample rate and
channel count are kept for the format check after each start (boot log: `… Hz, … ch`).

**Clean starts and format checks** (`pump_starts_()`, `check_formats_()`, every loop):
- ESPHome's `AudioPipeline` passes a stream's format to its speaker once, when the speaker starts; a new URL or
  file on a pipeline that still runs reuses it, and the resampler keeps converting from the previous format.
  `start_stream_()` and `start_announcement_()` therefore send one STOP if needed and start only when the player
  is no longer `PLAYING` / `ANNOUNCING` and the resampler `is_stopped()` (after 4 s / 3 s they start anyway, with
  a warning, and the format check catches a stale chain).
- Stored sounds: about 300 ms after the start, the announcement resampler's `get_audio_stream_info()` must match
  the slot's scanned rate and channels; one restart otherwise.
- Streams: the fix is in ESPHome's own pipeline (`components/speaker`, ATHAN PATCH 1, README there). microMP3's
  probe locks onto the first four bytes that look like a header, a live stream is joined mid-frame, and at the
  first real frame the decoder reports `MP3_STREAM_INFO_CHANGED`; stations also change format between recordings.
  Upstream gives the speaker the format only once, so both played at the wrong speed. The patched pipeline gives a
  stopped speaker the new format whenever the decoder's changes (and stops a still-running speaker before the first
  one, which covers the player's own restarts too).
- Streams, backstop (MP3 only): `CHECK_STREAM` reads the first 12 KB with `http_get_(…, truncate)` and
  `mp3_scan()`s them (the first position where frames chain). It runs 10 s after a start (away from the station's
  start burst and the player's TLS handshake) and every 10 minutes. If it disagrees with the media resampler, it
  is read once more (the station may have changed format in between, which the pipeline follows); a second
  disagreement is silenced at once (`hard_stop_cb_`) and restarted cleanly, up to 3 times per stream, then the
  stream stops with an error.

**After the radio**: `stop_media_pipeline_()` sets `media_stop_pending_`, cleared once the media chain has stopped.
A stored sound (`play_slot()`: the athan, the tawashih, a preview from flash) waits for it in `pump_starts_()` (at
most 3 s): the radio's last half second is still in the resampler, mixer and I2S buffers and would play under the
new sound's start. Tones and the tick do not wait (the tick plays over the radio).

**End of a sound**: ESPHome's mixer ends a source only when the I2S speaker has reported all of its frames played
(`pending_playback_frames_`). When the I2S speaker restarts on its own ("Event/record queues desynced", "Partial DMA
write broke buffer alignment": its writer missed the 50 ms of DMA), the frames it held are dropped but stay counted
(`frames_in_pipeline_`); the next sound's mixer input starts with that count as its delay and never empties, and
the player keeps announcing until other audio plays. On the prototype every athan started over a running speaker
did this, and the athan screen stayed to `make_athan`'s 7 min timeout. The cause: the announcement reader fills its
ring buffer from flash in one `xRingbufferSend`, which ESP-IDF copies inside a critical section; at ESPHome's 1 MB
`buffer_size` that is far longer than 50 ms with interrupts off. `buffer_size` 128 KB fixed it (0 restarts in 6
starts, 3 of 3 before); athan.yaml now uses 48 KB, for the Wi-Fi (CLAUDE.md). As a bound, the end tracking in `loop()` stops a stored sound still announced 5 s
past its length (`AudioSlots::duration_ms`).

**Instant stops**: `hard_mute` mutes the I2S speaker and calls `begin_drain_watch()`, which notes the pipelines
whose resampler runs. `loop()` counts each resampler's stops (`media_stops_`, `announce_stops_`); `audio_drained()`
is true once each noted pipeline has stopped. A resampler stops only after its mixer input has, which stops once its
frames have played (or the I2S speaker stopped), so the unmute (`audio_drained()` or the I2S speaker stopped, at most
2 s) leaves no tail and does not cut what starts next.

**Download** (`DOWNLOAD_URL`):
1. Download into PSRAM. A `Content-Length` over the limit is refused before reading, and the read aborts as
   soon as it passes the limit. The selected entry is not downloaded at all (`selected_entry()`).
2. `mp3_scan()` needs three chained Layer III frames to sync (an ID3v2 tag is skipped). The duration is the sum
   of the frame durations.
3. Size and duration are checked against the slot's limits.
4. Handshake (section 4), erase, 4 KB bounce writes with progress, header last (with the link's CRC; an upload stores 0).

Any failure frees the buffer and leaves the slot as it was. A power cut during the write leaves no valid header,
so the slot is empty and the default comes back automatically.

**Upload** (`POST /audio/upload?slot=N`, multipart): `upload_begin` allocates limit + 1 bytes of PSRAM and claims
`sound_busy_`. `upload_data` appends, marking `overflow` past the limit. `upload_end` either reports "too big"
or queues `COMMIT_BUFFER`, which runs steps 2–4 above.

## 6. Lists and radio

- **Catalog** `docs/audio/catalog.json` (≤ 64 KB): lists `athan`, `fajr`, `tawashih`, `tick`, each ≤ 10
  `{name, url}`. A relative URL resolves against `<data_url>/audio/`. It is fetched at boot, then every 12 h
  (retry every 1 min on failure), and kept in RAM only.
- **Stations** `docs/radio/stations.json` (≤ 16 KB): 10 `{name, url}`, kept in memory (`stations_`). Fetched at
  boot and every 6 h (retry every 1 min until a first copy exists, then every 30 min), and early when a
  subscribed station gives up after 6 reconnects (about a minute) (at most every 10 min, `stations_fetched_at_`). `radio_play()`
  uses the copy in memory at once; only without any copy it queues `STATION_PLAY` (fetch, then play; a waiting
  one is replaced, not doubled, `enqueue_(job, true)`). The yaml labels the Radio Station select options from it
  (fixed buffers, rewritten in place; the select is synced by index).
- **`radio_play(slot, subscribed)`:** a subscribed slot plays the link from the list in memory (or queues
  `STATION_PLAY` when no list was ever loaded), an own slot plays the slot's `text` entity (`radio_url_N`). Each play bumps `radio_token_`, so a stale answer from an older request is
  dropped.
- **`radio_tick_()`:** sound means the media speaker runs, never the player's state. A link that fails leaves the
  player idle at once (`components/speaker`, ATHAN PATCH 2: upstream reopens it many times a second, for ever), and
  it tries again 3, 6 and 9 s later; a link that stays open without sound gets 20 s. Then it gives up with "station
  not reachable".
- **`net_watch_()`** (every loop): the network gone stops a stream at once (a streamed preview ends; the radio
  waits, "waiting for Wi-Fi") and the radio starts again when it is back, or goes off after 10 minutes.
  `radio_play()` without network waits the same way.
- **The yaml side:**
  - `make_athan` and `run_prefajr` save `radio_active()` into `radio_resume`, stop the radio, and restart that
    slot when they finish.
  - `silence_audio` clears `radio_resume`.
  - `play_tick` ducks `media_mixer_input` by 20 dB.

## 7. Prayer times

**Store** (`prayer` partition, 8 × 16 KB slots):
- Each slot is a header sector (`magic "PTY1"`, `version`, `seq`, `key[32]`, `year`, `days`, `tz[64]`,
  `table_crc`, `header_crc`) plus the table at +4 KB: `uint16` minutes per value, 12 per day.
- `write()` picks a free slot or the least useful one, never one in the keep list (key's year−1, year,
  year+1), and writes the header last. If duplicates exist, the highest `seq` wins.

**Device checks** (`parse_year_file`): `prayertimes_specs.md` "What the clock checks".

**`prayer_tick_()`** (main loop, every second, after the clock is valid):
1. Loads the current and previous year's tables for the location (`load_tables_`), and applies the time zone
   from the stored year (`apply_tz_` → `time::ParsedTimezone` → `time::set_global_tz`).
2. Bumps `schedule_version_` at a new day of year.
3. Publishes the status line.
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

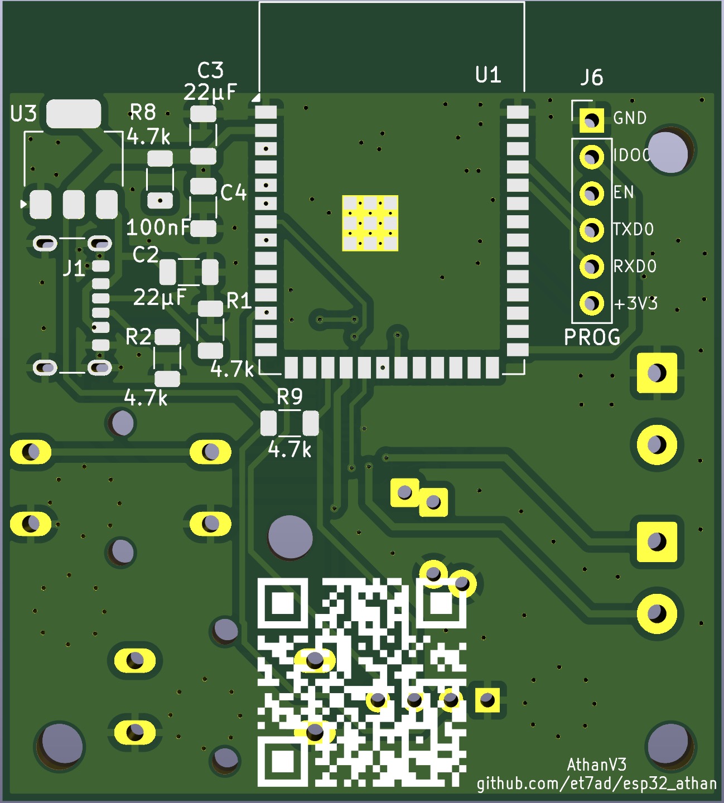
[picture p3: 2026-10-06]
hardware/pcb/generated_imgs_and_3d/Front_no_3D.jpg

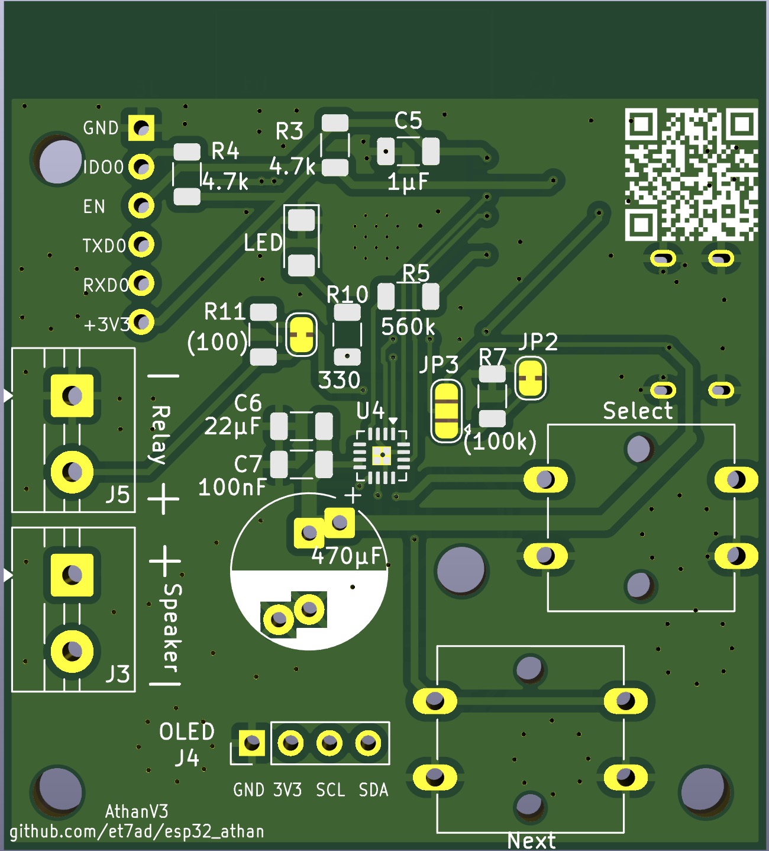
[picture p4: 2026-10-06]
hardware/pcb/generated_imgs_and_3d/Back_no_3D.jpg

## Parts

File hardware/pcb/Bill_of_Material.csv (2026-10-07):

Reference | Qty | Value | Footprint | Datasheet | Description
C1 | 1 | 470µF | Capacitor_THT:CP_Radial_D10.0mm_P5.00mm_P7.50mm |  | Polarized capacitor
C2,C3,C6 | 3 | 22µF | Capacitor_SMD:C_1206_3216Metric |  | Unpolarized capacitor
C4,C7 | 2 | 100nF | Capacitor_SMD:C_1206_3216Metric |  | Unpolarized capacitor
C5 | 1 | 1µF | Capacitor_SMD:C_1206_3216Metric |  | Unpolarized capacitor
D1 | 1 | LED | LED_SMD:LED_1206_3216Metric_Pad1.42x1.75mm_HandSolder |  | Light emitting diode
J1 | 1 | USB_C_Receptacle_PowerOnly_6P | Connector_USB:USB_C_Receptacle_GCT_USB4125-xx-x_6P_TopMnt_Horizontal | https://www.usb.org/sites/default/files/documents/usb_type-c.zip | USB Power-Only 6P Type-C Receptacle connector
J3 | 1 | Speaker | TerminalBlock:TerminalBlock_MaiXu_MX126-5.0-02P_1x02_P5.00mm |  | speaker 4Ω 3W
J4 | 1 | OLED | Connector_PinHeader_2.54mm:PinHeader_1x04_P2.54mm_Vertical |  | Generic connector, single row, 01x04, script generated (kicad-library-utils/schlib/autogen/connector/)
J5 | 1 | Relay | TerminalBlock:TerminalBlock_MaiXu_MX126-5.0-02P_1x02_P5.00mm |  | Relay
J6 | 1 | PROG | Connector_PinHeader_2.54mm:PinHeader_1x06_P2.54mm_Vertical |  | Generic connector, single row, 01x06, script generated (kicad-library-utils/schlib/autogen/connector/)
R1,R2,R3,R4,R5,R8,R9 | 7 | 4.7k | Resistor_SMD:R_1206_3216Metric |  | Range 4.08–6.12k,Range 4.7-10k,Resistor,Resistor with allowed range of 4.7–10k [Left]
R7 | 1 | (100k) | Resistor_SMD:R_1206_3216Metric |  | Optional for selecting 15dB (cut Solder Jumper)
R10 | 1 | 330 | Resistor_SMD:R_1206_3216Metric |  | Resistor with allowed range of 470–680k only
R11 | 1 | (100) | Resistor_SMD:R_1206_3216Metric |  | Optional with the SolderJumper
SW1 | 1 | SKRHABE010 | SKRHABE010:SW-SMD_SKRHABE010 | https://lcsc.com/product-detail/5-way-Tactile-Switchs_ALPS_SKRHABE010_SKRHABE010_C139794.html
U1 | 1 | ESP32-S3-WROOM-1-N16R8 | RF_Module:ESP32-S3-WROOM-1 | https://www.espressif.com/sites/default/files/documentation/esp32-s3-wroom-1_wroom-1u_datasheet_en.pdf | RF Module, ESP32-S3 SoC, Wi-Fi 802.11b/g/n, Bluetooth, BLE, 32-bit, 3.3V, onboard antenna, SMD
U3 | 1 | AMS1117-3.3 | Package_TO_SOT_SMD:SOT-223-3_TabPin2 | http://www.advanced-monolithic.com/pdf/ds1117.pdf | 1A Low Dropout regulator, positive, 3.3V fixed output, SOT-223
U4 | 1 | MAX98357A | Package_DFN_QFN:TQFN-16-1EP_3x3mm_P0.5mm_EP1.23x1.23mm | https://www.analog.com/media/en/technical-documentation/data-sheets/MAX98357A-MAX98357B.pdf | Mono DAC with amplifier, I2S, PCM, TDM, 32-bit, 96khz, 3.2W, TQFP-16

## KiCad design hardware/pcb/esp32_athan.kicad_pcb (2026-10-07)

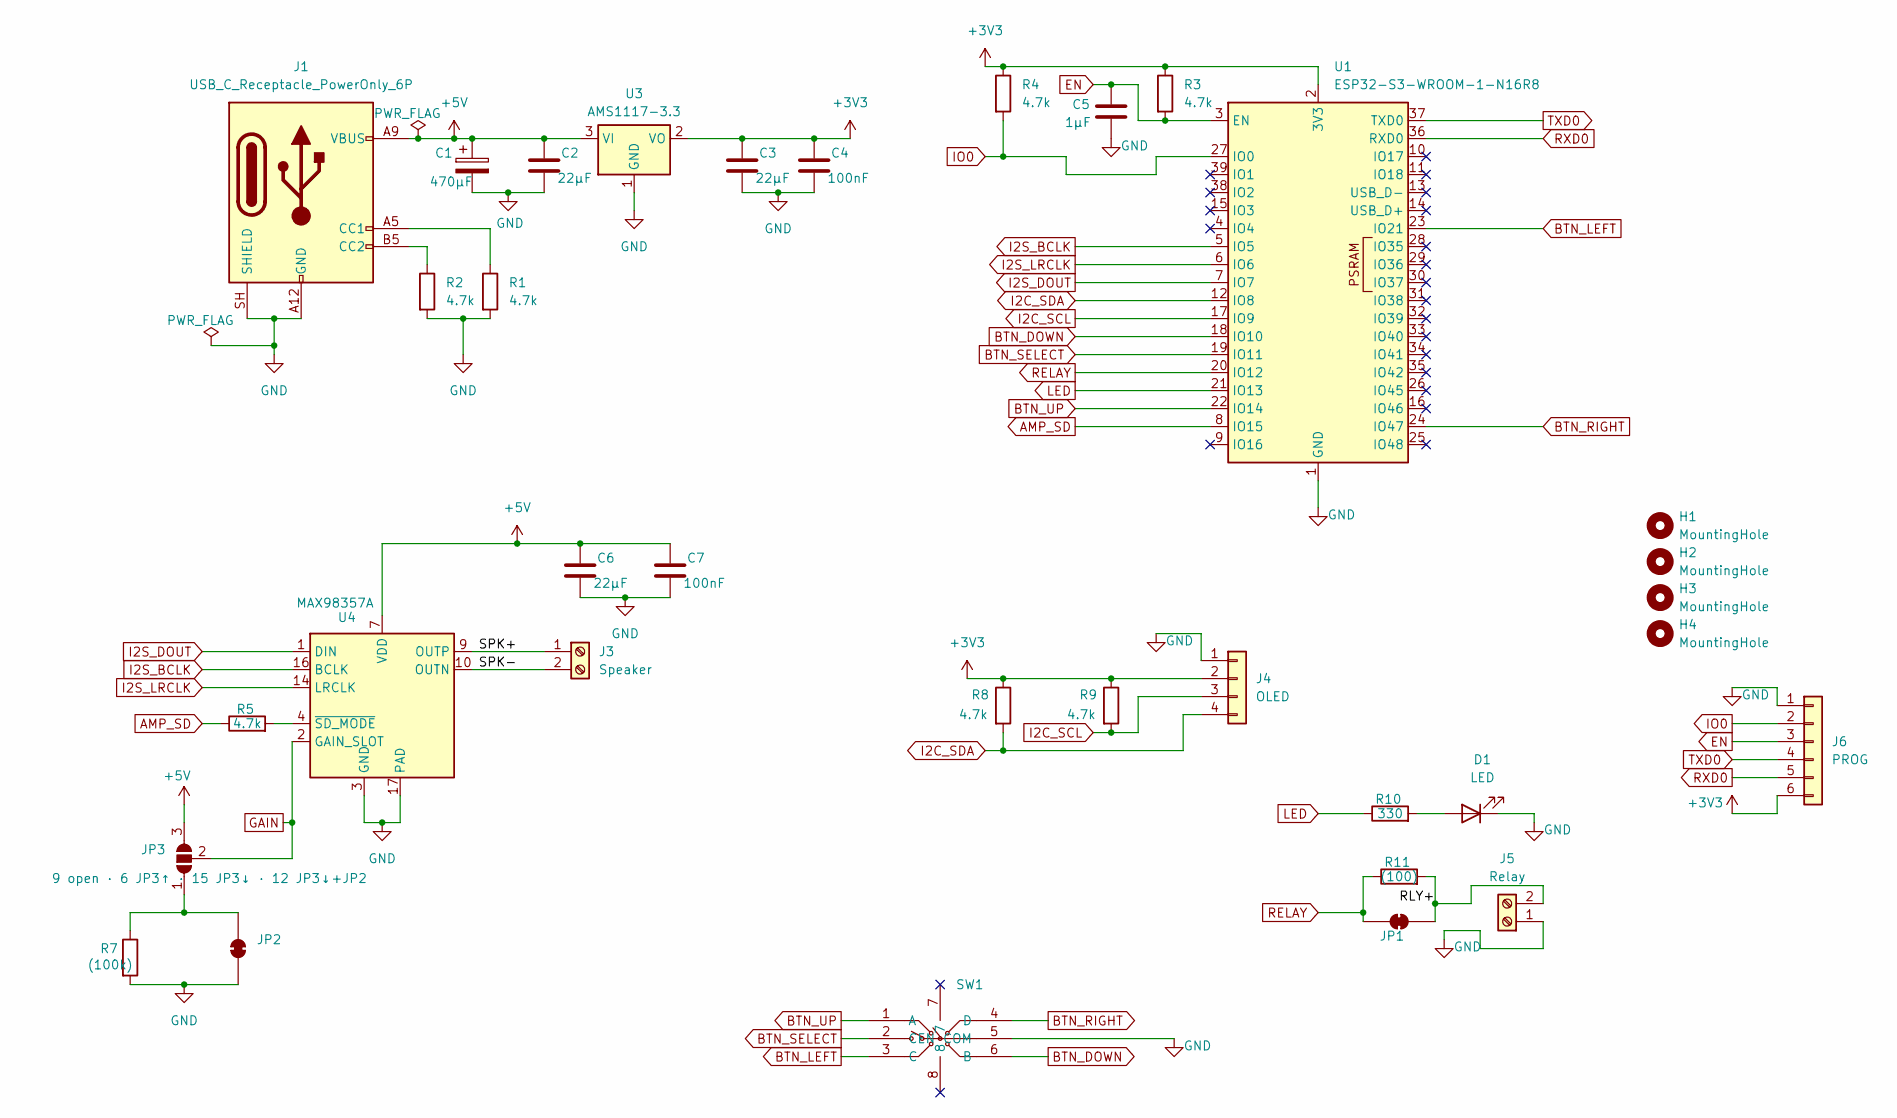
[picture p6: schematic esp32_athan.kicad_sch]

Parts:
C1: 470µF; CP_Radial_D10.0mm_P5.00mm_P7.50mm
C2, C3, C6: 22µF; C_1206_3216Metric
C4, C7: 100nF; C_1206_3216Metric
C5: 1µF; C_1206_3216Metric
D1: LED; LED_1206_3216Metric_Pad1.42x1.75mm_HandSolder
H1, H2, H3, H4: MountingHole; MountingHole_3.2mm_M3
J1: USB_C_Receptacle_PowerOnly_6P; USB_C_Receptacle_GCT_USB4125-xx-x_6P_TopMnt_Horizontal
J3: Speaker; TerminalBlock_MaiXu_MX126-5.0-02P_1x02_P5.00mm
J4: OLED; PinHeader_1x04_P2.54mm_Vertical
J5: Relay; TerminalBlock_MaiXu_MX126-5.0-02P_1x02_P5.00mm
J6: PROG; PinHeader_1x06_P2.54mm_Vertical
JP1, JP2: SolderJumper_2_Bridged; SolderJumper-2_P1.3mm_Bridged_RoundedPad1.0x1.5mm
JP3: SolderJumper_3_Open; SolderJumper-3_P1.3mm_Open_RoundedPad1.0x1.5mm
R1, R2, R3, R4, R5, R8, R9: 4.7k; R_1206_3216Metric
R7: (100k); R_1206_3216Metric
R10: 330; R_1206_3216Metric
R11: (100); R_1206_3216Metric
SW1: SKRHABE010; SW-SMD_SKRHABE010; MPN SKRHABE010; LCSC Part C139794
U1: ESP32-S3-WROOM-1-N16R8; ESP32-S3-WROOM-1
U3: AMS1117-3.3; SOT-223-3_TabPin2
U4: MAX98357A; TQFN-16-1EP_3x3mm_P0.5mm_EP1.23x1.23mm

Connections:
+3V3: C3.1, C4.1, J4.2, J6.6, R3.1, R4.1, R8.1, R9.1, U1.2 (3V3), U3.2 (VO)
+5V: C1.1, C2.1, C6.1, C7.1, J1.A9 (VBUS), J1.B9 (VBUS), JP3.3 (B), U3.3 (VI), U4.7 (VDD), U4.8 (VDD)
/RLY+: J5.2, JP1.2 (B), R11.2
/SPK+: J3.1, U4.9 (OUTP)
/SPK-: J3.2, U4.10 (OUTN)
AMP_SD: R5.1, U1.8 (IO15)
BTN_DOWN: SW1.6 (B), U1.18 (IO10)
BTN_LEFT: SW1.3 (C), U1.23 (IO21)
BTN_RIGHT: SW1.4 (D), U1.24 (IO47)
BTN_SELECT: SW1.2 (CEN), U1.19 (IO11)
BTN_UP: SW1.1 (A), U1.22 (IO14)
EN: C5.1, J6.3, R3.2, U1.3 (EN)
GAIN: JP3.2 (C), U4.2 (GAIN_SLOT)
GND: C1.2, C2.2, C3.2, C4.2, C5.2, C6.2, C7.2, D1.1 (K), J1.A12 (GND), J1.B12 (GND), J1.SH (SHIELD), J4.1, J5.1, J6.1, JP2.1 (A), R1.2, R2.2, R7.2, SW1.5 (COM), U1.1 (GND), U1.40 (GND), U1.41 (GND), U3.1 (GND), U4.3 (GND), U4.11 (GND), U4.15 (GND), U4.17 (PAD)
I2C_SCL: J4.3, R9.2, U1.17 (IO9)
I2C_SDA: J4.4, R8.2, U1.12 (IO8)
I2S_BCLK: U1.5 (IO5), U4.16 (BCLK)
I2S_DOUT: U1.7 (IO7), U4.1 (DIN)
I2S_LRCLK: U1.6 (IO6), U4.14 (LRCLK)
IO0: J6.2, R4.2, U1.27 (IO0)
LED: R10.1, U1.21 (IO13)
unnamed: D1.2 (A), R10.2
unnamed: J1.A5 (CC1), R1.1
unnamed: J1.B5 (CC2), R2.1
unnamed: JP2.2 (B), JP3.1 (A), R7.1
unnamed: R5.2, U4.4 (~SD_MODE)
RELAY: JP1.1 (A), R11.1, U1.20 (IO12)
RXD0: J6.5, U1.36 (RXD0)
TXD0: J6.4, U1.37 (TXD0)

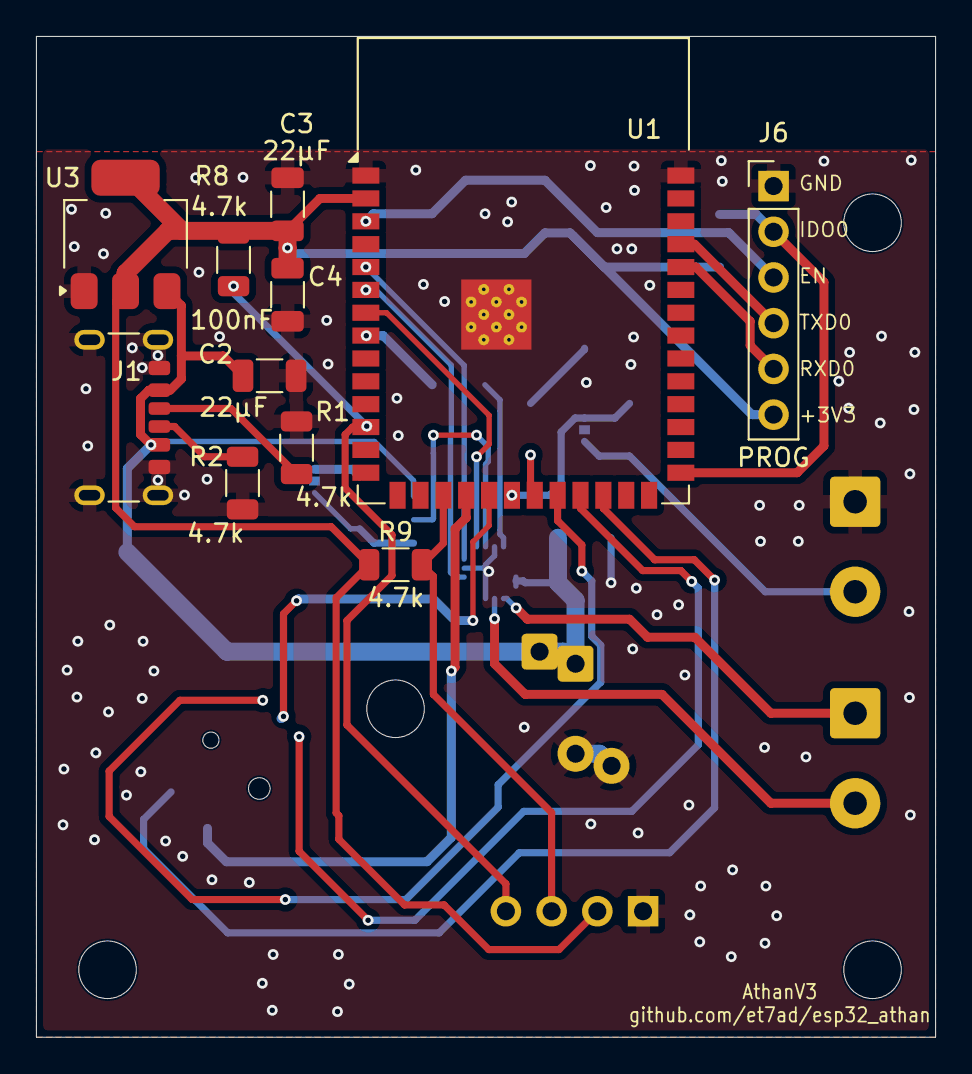
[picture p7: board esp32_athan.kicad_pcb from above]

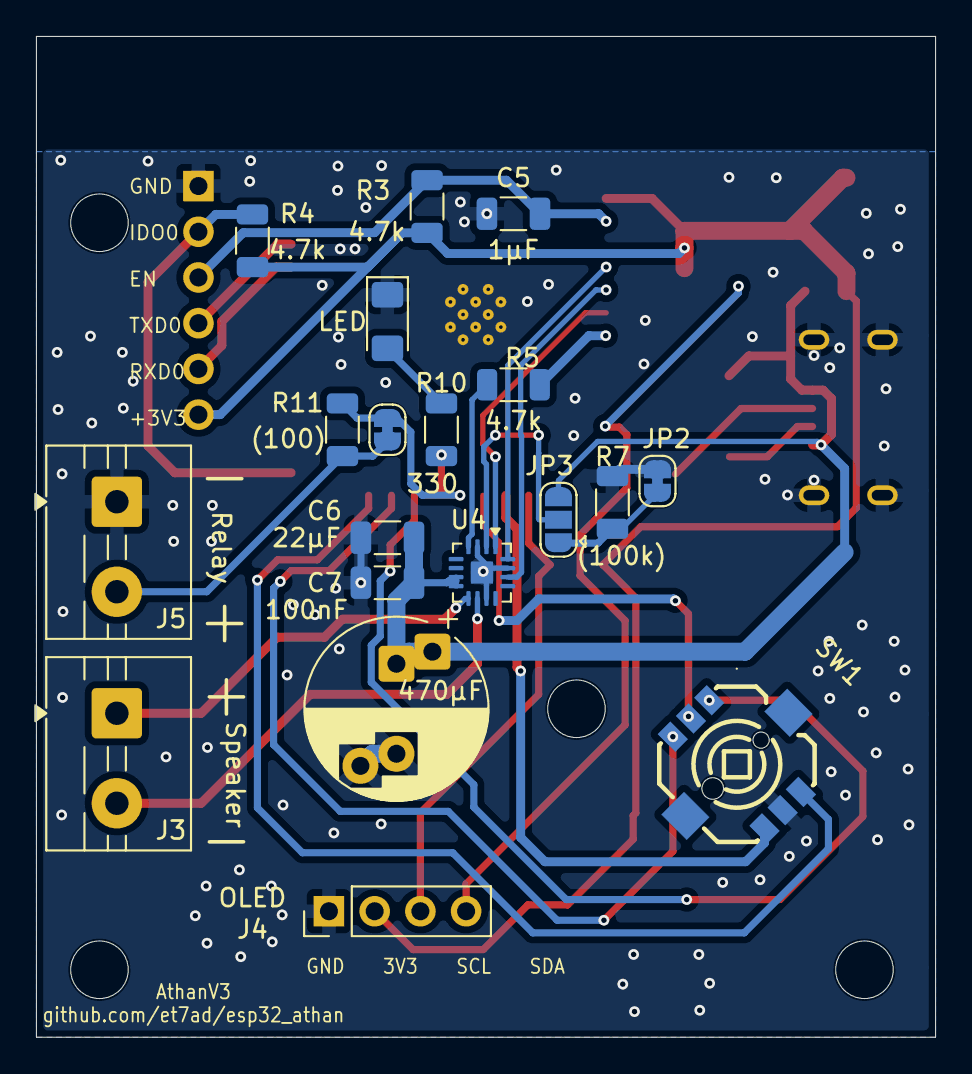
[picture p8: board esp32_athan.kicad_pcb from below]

Board: 2 copper layers, 50.0 x 55.6 mm, 34 parts (19 on the bottom side), 29 nets.

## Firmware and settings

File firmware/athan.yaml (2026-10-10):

# =====================================================================================================================
# Athan clock, version 3: ESP32-S3-WROOM-1-N16R8 + MAX98357A. ESPHome 2026.9 or newer.
#
#   Build:   esphome run firmware/athan.yaml        (first flash over USB-C: it also writes partitions.csv)
#   Docs:    README.md (owners), DEVELOPER.md (internals), version3_planning.md (design), CLAUDE.md (agents)
#
# Before the first build, put the two menu tones in firmware/sounds/ (README "Building"):
#   sounds/click.mp3   (menu click,   V2 file C3)      sounds/volume.mp3  (volume tone, V2 file C2)
#
# Behaviour lives here (menus, schedule, web entities). What ESPHome lacks (replaceable sounds in flash, the
# GitHub lists, radio subscriptions, yearly prayer files, runtime time zone, the /audio page) is the custom
# component in components/athan/.
# =====================================================================================================================

substitutions:
  device_name: athan
  friendly_name: Athan
  project_version: "3.0.0"
  # This repository's docs/ folder over HTTPS (lists, stations, yearly prayer files)
  data_url: "https://raw.githubusercontent.com/et7ad/esp32_athan/main/docs"
  # Firmware updates: manifest attached to the latest GitHub Release (scripts/make_release_manifest.py)
  update_manifest: "https://github.com/et7ad/esp32_athan/releases/latest/download/manifest.json"

  # Serial log level. DEBUG while testing: the log is how a crash or restart gets explained. For a finished build,
  # WARN keeps only warnings and errors (smaller, a little less work per event); NONE removes the log entirely.
  # Choices: NONE, ERROR, WARN, INFO, DEBUG, VERBOSE.
  log_level: DEBUG

  # Pins: HARDWARE.md 3.2 (also version3_planning.md section 3.3)
  pin_i2s_bclk: GPIO5
  pin_i2s_lrclk: GPIO6
  pin_i2s_dout: GPIO7
  pin_amp_sd: GPIO15       # MAX98357A SD_MODE through 4.7 kOhm: high = on (left channel), low/floating = off
  pin_sda: GPIO8
  pin_scl: GPIO9
  # The 5-way switch: each direction and the centre push switch to GND (internal pull-ups). Any of the five
  # may be swapped here to suit the board's routing.
  pin_up: GPIO14
  pin_down: GPIO10
  pin_left: GPIO21
  pin_right: GPIO47
  pin_select: GPIO11       # centre push
  pin_relay: GPIO12
  pin_led: GPIO13

  # OLED orientation / contrast
  oled_flip_x: "true"
  oled_flip_y: "true"
  oled_contrast: "1.0"

  # Volume curve: 10 % plays this many dB below full, rising evenly to 100 % = full (0 % = silent).
  # Larger = quieter low end. ESPHome's own curve spans 49 dB, which made 50 % only -24.5 dB.
  volume_range_db: "30"

  # Pre-Fajr Tawashih: minutes before Fajr, and how long the relay stays on
  prefajr_offset_min: "25"
  prefajr_relay_min: "15"
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

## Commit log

2026-10-06 Created schematic, next step is to assign footprints then make PCB
    [esp32_athan.kicad_pcb, esp32_athan.kicad_sch, partitions.csv]
2026-10-06 layout finished and ready for test production
    [Bill_of_Material.csv, Bill_of_Material_Goup_By_Description.csv, esp32_athan.kicad_pcb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]
2026-10-07 fix audio files + firmware bugs/improvements
    [athan.yaml]
2026-10-07 removing ETag handling for currently installed audios + adjusting language to use select/download instead of install for audio files + volume bugs fixing
    [athan.yaml]
2026-10-07 many bug fixes and adaptation to new buttons .. still in progress
    [athan.yaml]
2026-10-07 update schematic and layout with new resistance and new 5-way button instead of select,next
    [Bill_of_Material.csv, Bill_of_Material_Goup_By_Description.csv, esp32_athan.kicad_pcb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]
2026-10-07 some performance and RAM optimizaiton + attempting to fix losing connection while radio on
    [athan.yaml]
2026-10-08 Improve stability versy changed-pitch audio and wifi dropping. Add Speaker Media Player Component with Automation Support
    - Introduced `SpeakerMediaPlayer` class to handle media playback and announcements using two separate audio pipelines.
    - Implemented `PlayOnDeviceMediaAction` for triggering audio playback through automation.
    - Added support for volume control, mute state, and playlist management.
    - Created a new `Speaker` class to manage audio playback and state.
    - Included tests to ensure the integrity of the speaker component and its overrides.
    - Updated syntax check scripts to validate the new speaker implementation.
    [athan.yaml]
2026-10-08 fix audio keeping audio player busy after finished and optimizing the read buffer size
    [athan.yaml]
2026-10-08 improve startup after fresh wifi reset sequence
    [athan.yaml]
2026-10-14 Add colour TFT build option, screen settings and the drawn PCB
    Display
    - The display is chosen at build time: display_type oled|tft, or --display in
    build_firmware.sh and flash_firmware.sh. Each display's code lives in
    firmware/displays/{oled,tft}.yaml. A TFT build has its own release files and
    manifest (manifest-tft.json), so a clock only updates to its own build.
    - 240x240 ST7789 TFT (mipi_spi):
    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
2026-10-15 Lists of any length, full code review fixes, 44.1 kHz sounds, PCB v5
    Sound lists
    - The suggested lists (athan, Fajr, tawashih, tick) can have any number of
    entries, numbered in file order ("2. Abdul Basit") in the menu, on /audio
    and on the web page; long names wrap or shorten to fit both displays.
    - /audio: one form per sound, with its whole list in a dropdown (the one in
    use marked with a check mark) and Preview / Download buttons; the status
    bar says "downloaded and in use" and offers Reload page when the lists change.
    - Radio stays at 10 stations; README shows how to add one from mp3quran.net,
    with screenshots.
    Screen and windows
    - Tick window: from Fajr or Dhuhr until Maghrib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
2026-10-16 Guides for owners and builders, update mark, JLCPCB assembly files
    Docs
    - README is now a short landing page: the board picture (front and back,
    to scale, with the 1.54" screen showing the clock), the note for
    version 2 owners, why the prayer times come from this repository, then
    the 2.4 GHz warning, first setup, the joystick, the web page, updates
    and links to the guides.
    - New guides/: using.md (setup, screen, keys and menu, web page, sounds,
    radio, prayer times, updates), building.md (prototype, firmware build
    and flash, the board, acceptance checklist), maintaining.md (prayer
    times, sounds, stations, releases) and jlcpcb_assembly.md (ordering the
    board assembled).
    - HARDW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
2026-10-16 USB-C on either side, switch named by its real part, STEP out of the repo
    Board
    - J1 has a new footprint, USB_C_Receptacle_GCT_USB4125_6P_BothSides
    (project library): KiCad's GCT USB4125 with its six pads also on the
    back, the four shell legs in shared holes. The receptacle can be
    soldered on the front by hand or placed on the back by JLCPCB. Flipped
    onto the back, its A and B pins land on each other's pads: CC1 and CC2
    swap (each has its own 4.7 kΩ), VBUS and GND stay on their nets.
    - Copper at J1 rearranged for the back pads: the two +5V vias moved
    1.1 mm right, VBUS pads on both sides tracked to them, and two vias take
    the back CC pads to the front lines to R1 and R2.
    - A +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
2026-10-17 programmer hardware small pcb added
2026-10-18 Dynamic Mosque list loaded from mosques.json, numbered names, coordinates
    Mosque list
    - The Location list comes from docs/athantimes/mosques.json at runtime
    instead of being built into the firmware: any number of mosques, in the
    file's order, numbered ("1. Islamic Center of Davis") in the menu and on
    the web page. A new mosque needs no firmware update; "active": false
    keeps one off the list.
    - The clock stores only the mosque's key and shows names; owners never
    see keys. It saves its own mosque's name and coordinates, so a list that
    lacks it (not loaded yet, or switched off) still shows it by name. The
    Prayer Data line no longer starts with the key.
    - Colour screen: the Locatio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
2026-10-20 Click-together case with a plug-in display, TFT comes back after a replug
    Case (hardware/enclosure, now in the repo)
    - The board clicks into the back (two ledges under its bottom edge, two
    hooks over its top edge, ribs to centre it), the display clicks into
    the front (glass in a pocket behind the window, its board's bottom edge
    in two grooved stops, two springs over its sides), and the front clicks
    onto the back. Six M3 x 16 screws are optional, for extra hold.
    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
2026-10-21 Project website on GitHub Pages, and the case's board spring and knob
    The website (GitHub Pages from main, /docs: https://et7ad.github.io/esp32_athan/)
    - docs/*.html and docs/assets/: plain HTML and ES modules, no build step;
    docs/.nojekyll serves the folder as it is, and 404.html works at any
    wrong address.
    - Home: the clock's front drawn to scale from enclosure.py, with a live
    colour screen whose joystick and arrow keys open the real menu; today's
    times for the chosen mosque; a path for each kind of visitor; how a
    mosque's timetable reaches the clocks.
    - Set up: the four steps, with Bluetooth, iPhone hotspot and Home
    Assistant tabs, beside a live Wi-Fi setup screen that follows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
